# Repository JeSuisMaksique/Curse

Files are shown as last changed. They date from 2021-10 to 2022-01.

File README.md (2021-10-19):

# Curse
Репозиторий курсового проекта
Описание датчика.
Датчик замеряет температуру/влажность и отправляет данные по Wi-Fi с помощью модуля ESP-01S. При нажатии на кнопку можно отобразить текущие показания на OLED дисплее.

Датчика включает:
1. Плату обработки;
2. Модуль ESP-01S;
3. OLED дисплей.

Функции платы обработки:
1. Периодический опрос датчика AHT20 по i2c и получение данных о температуре и влажности;
2. Передача полученных данных с помощью модуля ESP-01S;
3. Периодичский контроль заряда аккумулятора с помощью АЦП. При низком заряде аккумклятора датчик передаёт информацию о разряде аккумуляора по Wi-Fi с помощью ESP-01S.

Основную часть времени модуль ESP-01S находится в режие сна и активируется только для передачи данных

Плата обработки (v.0.1):
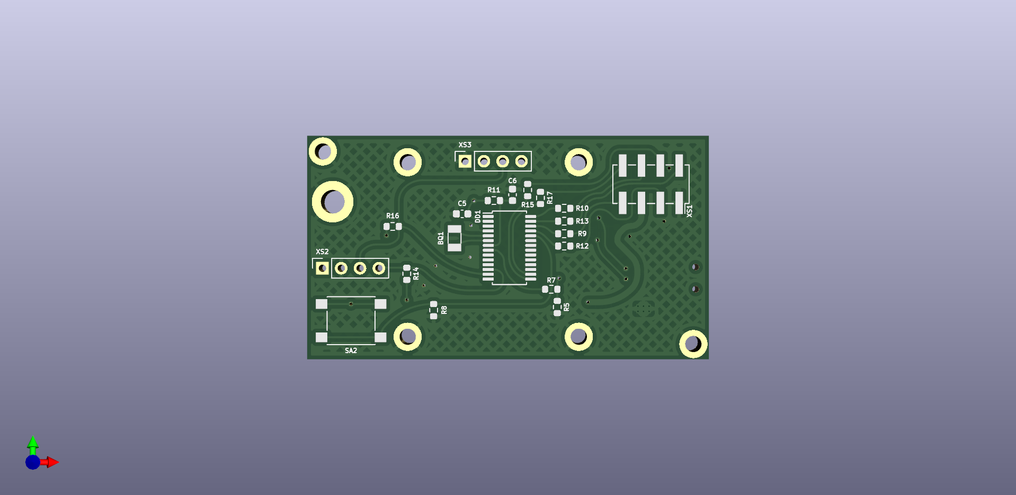
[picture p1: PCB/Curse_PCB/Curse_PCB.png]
PCB_Render


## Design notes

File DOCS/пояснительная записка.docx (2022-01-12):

# Аннотация

В данной работе рассматривается задача разработки датчика для замера температуры и влажности с последующей отправкой данных по Wi-Fi с помощью модуля ESP-01S, либо отображении этих данных на встроенном OLED дисплее.

Составляется структурная и принципиальная схема устройства, производится подбор элементной базы, трассировка, размещение элементов на плате, создание прототипа корпуса прибора, а также сравнение с уже имеющимися прототипами на рынке и с серийными аналогами.

# Лист технического задания

1. Прибор – устройство для замера температуры и влажности;

2. Назначение – измерение температуры и влажности окружающей среды;

3. Тип датчика или сенсора – датчик измерения температуры и влажности;

4. Тип микроконтроллера – MSP430F2112;

5. АЦП – измерение напряжения аккумулятора для контроля разряда;

6. Устройство ввода – кнопки;

7. Устройство вывода – OLED дисплей;

8. Интерфейс связи с ПК – Wi-Fi;

9. Тип питания – автономное;

10. Габариты устройства не должны превышать 80 мм х 36 мм х 27 мм (ШВГ);

# Введение

С помощью датчика температуры и влажности можно обеспечить комфортные условия в доме, потому что его показатели помогут вовремя проветривать комнаты, регулировать отопительную систему. В настоящее такие датчики используются в жилых и нежилых помещениях. Под целевым назначением нежилого помещения обычно понимается вид деятельности, для ведения которой будет использовано данное помещение, например: торговые, производственные, складские, офисные, медицинские, образовательные и спортивные помещения. К жилым помещениям относятся: жилой дом, квартира или комната.

Датчик – небольшая микросхема, которая оснащена термистором и емкостным определителем влажности. Эти элементы и определяют влажность и температуру воздуха.

Датчики температуры и влажности широко применяются на различных промышленных предприятиях. Этот прибор используются для автоматизации и диспетчеризации, различного рода помещений и теплиц, а также технологических процессов. В настоящее время часто используется в системе «Умный дом». С их помощью происходит измерение температуры и влажности в системах автоматического контроля и регулировка технологических процессов. Их задача состоит в получении данных об измеряемой величине, преобразовании и передаче полученных сигналов.

В рамках данного курсового проекта разрабатывается устройство измерения температуры и влажности с возможностью передачи данных по беспроводному каналу связи и возможностью индикации текущих показаний на встроенном OLED дисплее, выполненном на основе модулей AHT20 (датчик температуры и влажности), ESP-01S (Wi-Fi модуль) и WEA012864MX (дисплейный модуль фирмы «Winstar»).

# 1. Обзор рынка

Существует широкий спектр приборов для измерения температуры и влажности как проводных, так и работающих от батареек или аккумуляторов. Некоторые модели имеют особенности, такие как: беспроводное подключение к автоматическому регулированию климата в помещении, оповещение о изменении микроклимата на телефон или с помощью звукового сигнала, отображение даты и времени. Для сравнения с разработанным устройством были выбраны три модели датчиков, которые приведены в таблице 1. Модели подобраны по следующим характеристикам: имеют низкую стоимость, обладают базовым функционалом.

Таблица 1 – Сравнение приборов

Наименование | Xiaomi Mijia Bluetooth Hygrothermograph 2 | Xiaomi MiJia Miaomiaoce E-Ink | Thermo TA318

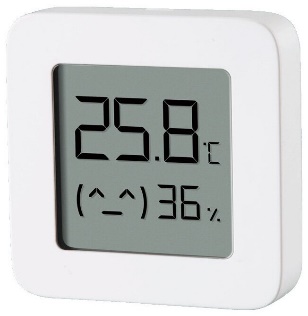
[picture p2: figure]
Метеостанция Xiaomi Mijia Bluetooth Hygrothermograph 2, белый
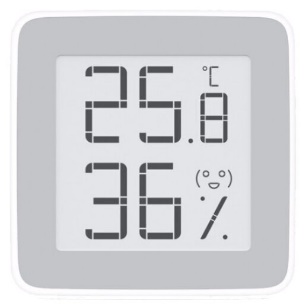
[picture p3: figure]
Метеостанция Xiaomi MiJia Miaomiaoce E-Ink, белый
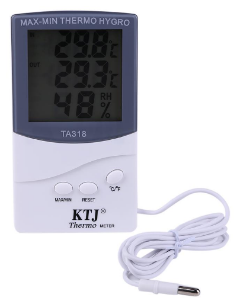
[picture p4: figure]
Метеостанция Thermo TA318 с выносным датчиком 1,5 м

Вид
Цена, руб. | 565 | 1140 | 970
Диапазон измерения температуры | -9-60° C | -0 - 60° C | -50 +70
Диапазон измерения влажности | 0-99.9% | - | -
Питание | автономное | автономное | автономное
Тип элемента питания | CR2032 | CR2032 | AAA
Расположение датчика | Внутреннее | Внутреннее | Выносной
Точность измерения температуры | - | 0.3° C | -
Точность измерения влажности | - | 3% | -
Беспроводной интерфейс | Bluetooth 4.2 BLE | Отсутствует | Отсутствует
Дополнительные функции | синхронизация со смартфоном | - | -

Большинство моделей на рынке представлены с дополнительными функциями. Прибор, разработанный в данном проекте, обладает только функциями измерения температуры и влажности и их дальнейшей отправкой по беспроводному каналу связи. Из-за того, что данное устройство будет являться штучным или мелкосерийным изделием, то стоимость будет гораздо выше, чем у массовых приборов такого же функционала.

# 2. Разработка устройства

Согласно техническому заданию, датчик температуры и влажности был разработан на базе модуля с датчиком температуры и влажности AHT20, OLED дисплея и модуля ESP-01S, которые подключены к микроконтроллеру MSP430F2112.

# 2.1 Структурная схема прибора и её описание

Устройство состоит из платы обработки с контроллером MSP430F2112, к которой подключены датчик AHT20, дисплейный модуль и Wi-Fi модуль ESP-01S. Структурная схема представлена на рисунке 1. Питание осуществляется от аккумулятора.

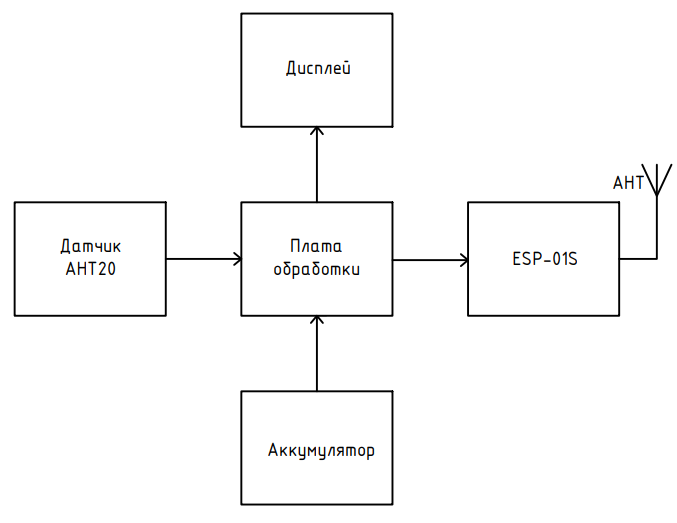
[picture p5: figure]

Рис. 1. Структурная схема устройства

# 2.2 Структура алгоритма программы для прибора

Большую часть времени устройство находится в режиме сна для экономии энергии. По таймеру один раз в минуту микроконтроллер опрашивает датчик температуры и влажности, и отправляет их на ПК по беспроводному каналу связи с помощью модуля ESP-01S. Также микроконтроллер периодически замеряет напряжение на аккумуляторе с помощью АЦП и, при низком напряжении, отправляет сигнал о низком заряде по беспроводному каналу связи. Также, при нажатии на кнопку происходит отображение текущих показаний на OLED дисплее в течение 10 секунд. Блок-схема алгоритма представлена на рисунке 2.

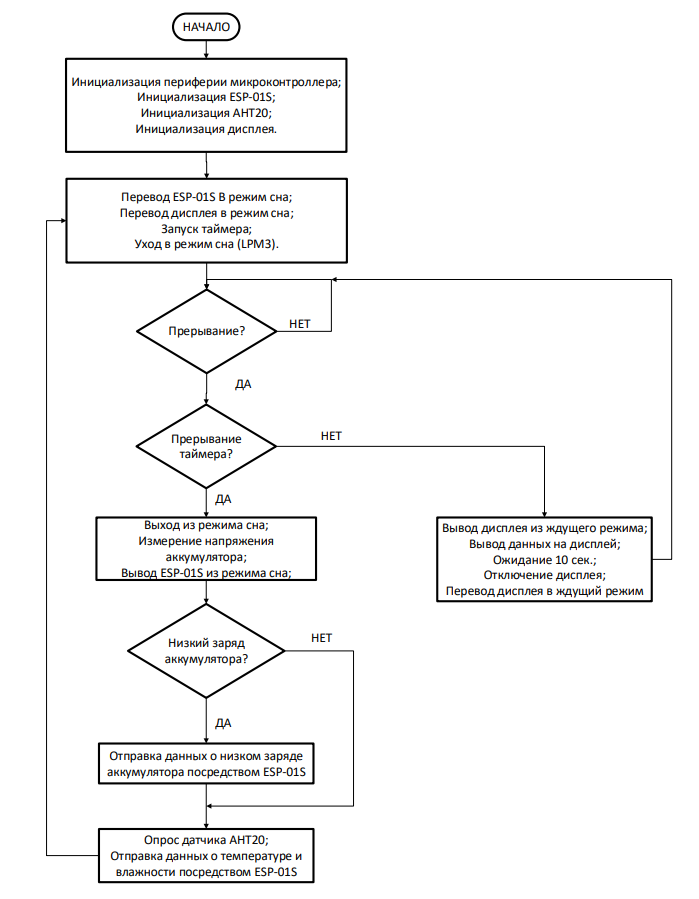
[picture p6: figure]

Рис. 2. Блок-схема алгоритма

# 2.3 Источник питания и общее потребление

Устройство питается с помощью литий-полимерного аккумулятора типоразмера 803040. В схеме предусмотрена возможность осуществлять зарядку аккумулятора через Micro USB разъём. Для этого в схеме (Рис. 3) присутствует микросхема для заряда BQ21040 «Texas Instruments» (DA2), а также защита от переразряда и перезаряда с помощью микросхемы BQ29737 «Texas Instruments» (DA1) и транзисторной сборки BUK9K5R1-30E «Nexperia». Микросхема DA1 замеряет напряжение аккумулятора и при слишком низком или слишком высоком напряжении отключает его от цепи для предотвращения нанесения ущерба аккумулятору.

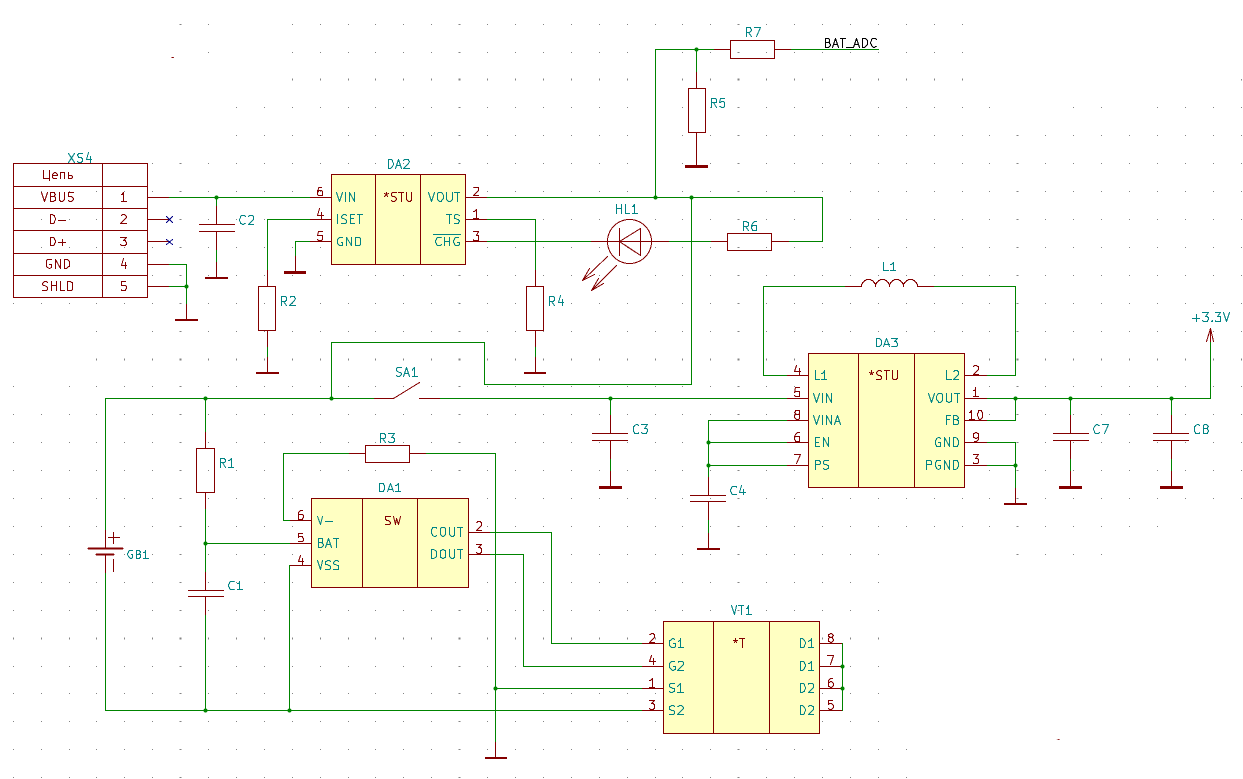
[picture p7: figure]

Рис. 3. Схема питания

За формирование рабочего напряжения 3,3 В отвечает микросхема TPS63061 «Texas Instruments» (DA3). TPS63061 представляют собой решение для питания от трех- и шестиэлементных щелочных, никель-кадмиевых или никель-металлгидридных аккумуляторов, а также одноэлементных или двухэлементных литий-ионных или литий-полимерных аккумуляторов. Выходные токи могут достигать 2 А при использовании двухэлементной литий-ионной или литий-полимерной батареи и разряжаться до 5 В или ниже. Понижающе-повышающий преобразователь основан на контроллере с фиксированной частотой и широтно-импульсной модуляцией (ШИМ), использующем синхронное выпрямление для достижения максимальной эффективности. При низких токах нагрузки преобразователь переходит в режим энергосбережения, чтобы поддерживать высокий КПД в широком диапазоне токов нагрузки. Режим энергосбережения можно отключить, заставив преобразователь работать на фиксированной частоте переключения. Максимальный средний ток в ключах ограничен типичным значением 2,25 А. Выходное напряжение программируется с помощью внешнего резисторного делителя или фиксируется внутри микросхемы[ссылка].

Основные потребители энергии:

1) Микроконтроллер MSP430F2112;
2) Дисплейный модуль WEA012864MX;
3) Wi-Fi модуль ESP-01S;
4) Модуль измерения температуры и влажности AHT20.

Потребление MSP430F2112. Основную часть времени контроллер находится в режиме энергосбережения (LPM3), в котором потребление составляет примерно 0,8 мкА при напряжении питания 3,3 В, с периодическим выходом в активный режим, в котором потребление составляет 450 мкА при напряжении питания 3,3 В. Среднее потребление при нахождении в активном режиме 10 секунд каждую минуту составит 45,72 мкА при напряжении питания 3,3 В.

Потребление модуля ESP-01S. По аналогии с MSP430 модуль ESP-01S находится в режиме сна, выходя из него только для передачи данных. В режиме сна потребление составляет 20 мкА при напряжении питания 3,3 В. В активном режиме при мощности передатчика 20 мВт (13 дБм) потребление составляет 120 мА при напряжении питания 3,3 В. В активный режим передатчик переходит раз в минуту и находится в нём в среднем одну секунду благодаря чему среднее потребление составит 2,05 мА при напряжении питания 3,3 В.

Потребление модуля AHT20. В режиме бездействия потребление составляет не более 250 нА при напряжении питания 3,3 В. В режиме измерения потребление составляет 23 мкА при напряжении питания 3,3 В. Режим измерения длится 80 мс и производится один раз в минуту. Среднее потребление при этом составит примерно 280 нА при напряжении питания 3,3 В.

Потребление дисплейного модуля WEA012864MX. В режиме ожидания драйвер дисплея SSD1306 потребляет не более 10 мкА при напряжении питания 3,3 В. В активном режиме дисплейный модуль потребляет 15 мА при напряжении питания 3,3 В при 50% заполнении дисплея. Так как периодическое включение дисплея отсутствует, то среднее потребление составляет 10 мкА при напряжении питания 3,3 В.

Данные о потреблении основных элементов представлены в таблице 2.

Таблица 2 – Потребления основных элементов

Потребитель | Потребление в ждущем режиме при напряжении 3,3 В, мА | Потребление в активном режиме при напряжении 3,3 В, мА | Среднее потребление при напряжении 3,3 В, мА | Среднее потребление, мВт
MSP430F2112 | 0,0008 | 0,45 | 0,0457 | 0,151
ESP-01S | 0,02 | 120 | 2,02 | 6,7
AHT20 | 0,00025 | 0,023 | 0,0003 | 0,0008
WEA012864MX | 0,01 | 15 | 0,01 | 0,033

Таким образом примерное среднее потребление устройства составляет примерно 6,85–7 мВт.

Предполагается использование литий-полимерного аккумулятора 803040-950 ёмкостью 950 мА/ч и номинальным напряжением 3.7 В, или 3,515 Вт/ч. Без учёта саморазряда аккумулятора и в случае соответствия номинальной ёмкости время автономной работы устройства от одного заряда составит примерно 513 часов или 21 день и 9 часов в случае измерения и передачи данных один раз в минуту. Время автономной работы можно увеличить путём увеличения интервала измерения и передачи данных. При этом максимальное потребление тока может составить примерно 136 мА при напряжении питания 3,3 В.

# 2.4 Дисплей

Дисплейный модуль WEA012864MX «Winstar» (Рис. 4) построен на базе OLED дисплея и драйвера SSD1306 [ссылка]. Дисплей подключается к шине I2C.

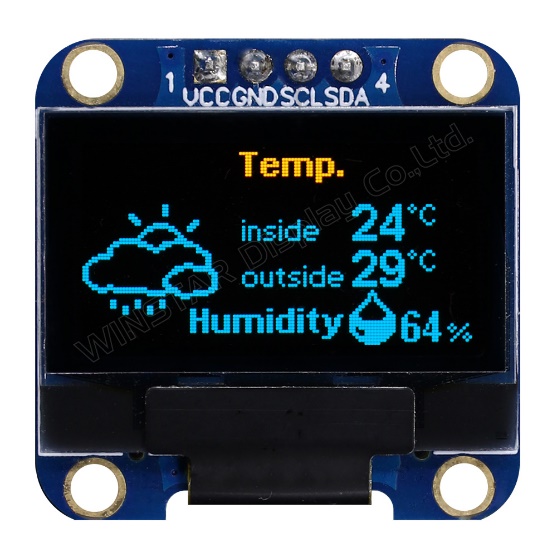
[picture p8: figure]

Рис. 4. Дисплейный модуль WEA012864MX

# 2.5 Модуль датчика влажности и температуры

Плата модуля содержит датчик температуры и относительной влажности AHT20 и его обвязку (рисунок 5). Датчик выдает цифровые сигнала в стандартном формате I2C. AHT20 оснащен микросхемой, улучшенным полупроводниковым емкостным датчиком влажности и стандартным встроенным датчиком температуры.

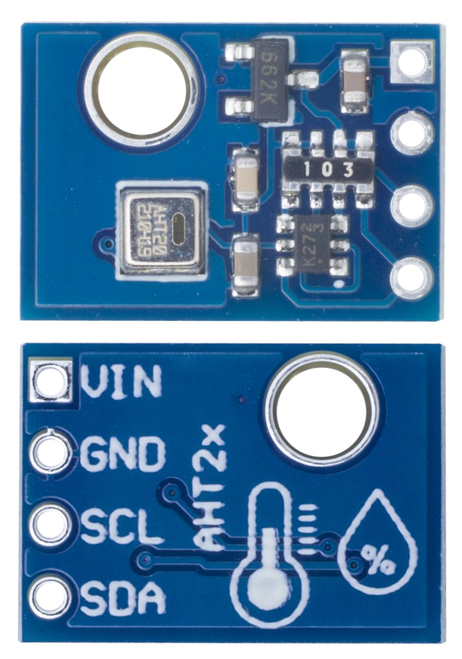
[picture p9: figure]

Рис. 5. Модуль датчика АНТ20

Технические характеристики[ссылка]:

1) Потребляемый ток – 23 мкА (в режиме измерения), в режиме покоя: 0,25 мкА;
2) Напряжение питания: 2–5,5 В;
3) Измеряет влажность в диапазоне от 0% до 100%. Погрешность может составлять до 2%;
4) Измеряет температуру в интервале от -40 до 85 °C (точность – 0,3 °C)

# 2.6 Микроконтроллер

Для обработки информации и взаимодействия со всеми элементами устройства был выбран микроконтроллер MSP430F2112 «Texas Instruments» (рисунок 6).

Данный микроконтроллер имеет следующие характеристики [ссылка]:

1) Диапазон напряжения питания: от 1,8 до 3,6 В;
2) Сверхнизкое энергопотребление (Активный режим: 250 мкА при 1 МГц, 2,2 В; Режим ожидания: 0,7 мкА);
3) Сверхбыстрый выход из режима ожидания менее чем за 1 мкс;
4) 10-битный аналого-цифровой преобразователь со скоростью 200 тыс/с с внутренним эталоном, выборкой и хранением, автосканированием и контроллером передачи данных;
5) Универсальный последовательный интерфейс связи (UART, SPI, I2C);
6) 2 КБ + 256 Б флэш-памяти и 256 байт ОЗУ.

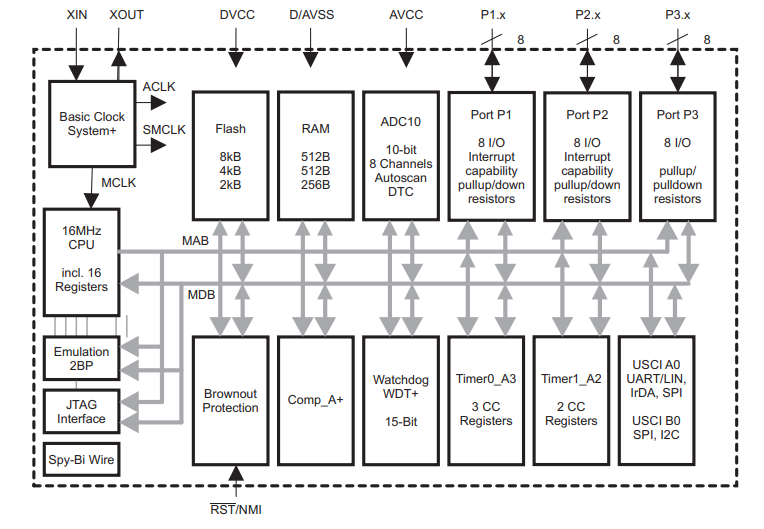
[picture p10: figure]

Рисунок 6 – Блок-схема микроконтроллера MSP430F2112

Разъёма программирования на плате не предусмотрено, так как предполагается, что программа будет записываться на этапе изготовления.

# 2.7 Модуль ESP-01S

ESP-01S — плата-модуль WiFi на базе популярного чипсета ESP8266EX (Рис. 7). На борту платы находится микросхема Flash-памяти объёмом 2 МБ, чип ESP8266EX, кварцевый резонатор, два индикаторных светодиода и микрополосковая антенна на верхнем слое печатной платы. Flash-память необходима для хранения программного обеспечения. При каждом включении питания, ПО автоматически загружается в чип ESP8266EX [ссылка].

По умолчанию модуль настроен на работу через «AT-команды». Управляющая плата посылает команды — Wi-Fi модуль выполняет соответствующую операцию.

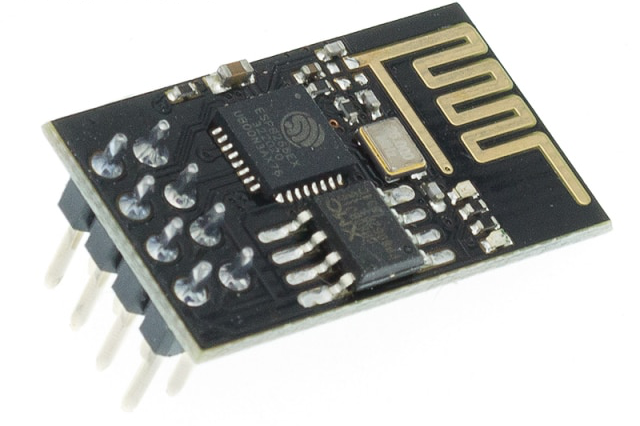
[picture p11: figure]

Рис. 7. Модуль ESP-01S

# 2.8. Разработка конструктива корпуса

Плату с размещенными на ней элементами необходимо поместить в корпус (Рис. 8). Для изготовления корпуса датчика температуры и влажности выбран АБС-пластик. АБС-пластик – ударопрочная техническая термопластическая смола на основе сополимера акрилонитрила с бутадиеном и стиролом. Этот вид пластмассы является нетоксичным и ударостойким. Предполагается использовать пластмассу белого цвета. Чертёж корпуса представлен в приложении ?.

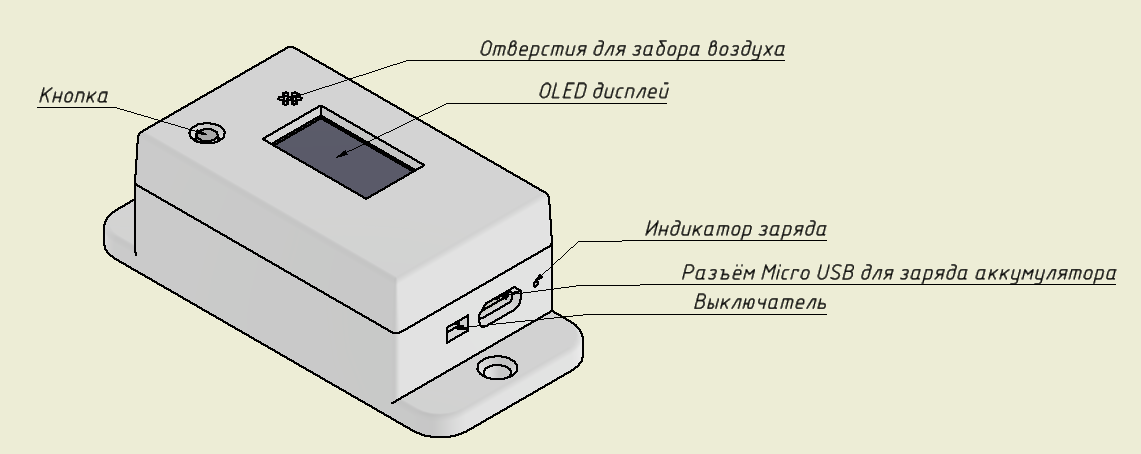
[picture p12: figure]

Рис. 8. Корпус

# 3. Расчет стоимости

Была рассчитана стоимость одного изделия из расчёта штучного производства и производства партии в 1000 штук.

Информация о стоимости ЭРИ взята с сайтов «Чип и Дип» (https://www.chipdip.ru/), «ДКО Электронщик» (https://www.electronshik.ru/) и «АлиЭкспресс» (https://aliexpress.ru/). Данные о стоимости ЭРИ представлены в таблице 3.

Таблица 3 – Стоимость ЭРИ

Наименование | Кол-во | Цена для 1 изделия | Цена для 1000 изделий | Итого для 1 изделия | Итого для 1000 изделий | Примечаиние
1 | 2 | 3 | 4 | 5 | 6 | 7
Кварцевый резонатор 32.768 kHz 03215C2 | 1 | 68,00 | 50,00 | 68 | 50000 | Чип и Дип
0.1 мкФ-NP0-50В ±10% 0603 | 3 | 12,00 | 2,00 | 36 | 6000 | Чип и Дип
1 мкФ-NP0-16В ±10% 0805 | 1 | 8,00 | 2,60 | 8 | 2600 | Чип и Дип
10 мкФ-NP0-16В ±5% 0805 | 3 | 10,00 | 4,20 | 30 | 12600 | Чип и Дип
2200 пФ-NP0-50В ±5% 0603 | 1 | 3,00 | 0,77 | 3 | 770 | Чип и Дип
BQ21040 | 1 | 232,02 | 114,58 | 232,02 | 114580 | ДКО Электронщик
BQ29737 | 1 | 48,34 | 16,86 | 48,34 | 16860 | ДКО Электронщик
MSP430F2112IPW | 1 | 110,00 | 137,70 | 110 | 137700 | ДКО Электронщик
TPS63031 | 1 | 126,00 | 126,00 | 126 | 126000 | ДКО Электронщик
TO-1608BC-MRE | 1 | 8,00 | 8,00 | 8 | 8000 | Чип и Дип

Продолжение таблицы 3
1 | 2 | 3 | 4 | 5 | 6 | 7
VLS252010CX-1R5M-1 | 1 | 59,65 | 32,79 | 59,65 | 32790 | ДКО Электронщик
1,0 кОм ±1% 0603 | 1 | 3,00 | 0,48 | 3 | 480 | Чип и Дип
1,5 кОм ±5% 0603 | 1 | 3,00 | 0,48 | 3 | 480 | Чип и Дип
10 кОм ±5% 0603 | 5 | 3,00 | 0,48 | 15 | 2400 | Чип и Дип
100 кОм ±5% 0603 | 1 | 3,00 | 0,48 | 3 | 480 | Чип и Дип
2,2 кОм ±5% 0603 | 1 | 3,00 | 0,48 | 3 | 480 | Чип и Дип
330 Ом ±5% 0603 | 1 | 3,00 | 0,48 | 3 | 480 | Чип и Дип
47 кОм ±5% 0603 | 1 | 3,00 | 0,48 | 3 | 480 | Чип и Дип
510 Ом ±5% 0603 | 6 | 3,00 | 0,48 | 18 | 2880 | Чип и Дип
PCM12SMTR | 1 | 72,50 | 56,00 | 72,5 | 56000 | ДКО Электронщик
2-1977223-9 | 1 | 60,09 | 23,72 | 60,09 | 23720 | ДКО Электронщик
BUK9K5R1-30E | 1 | 44,87 | 42,07 | 44,87 | 42070 | ДКО Электронщик
DS-1023 - 2x4 | 1 | 4,12 | 2,76 | 4,12 | 2760 | ДКО Электронщик
DS-1023 - 1x4 | 2 | 1,70 | 1,30 | 3,4 | 2600 | ДКО Электронщик
47346-0001 | 1 | 20,00 | 15,20 | 20 | 15200 | ДКО Электронщик
Аккумулятор LP803040 | 1 | 398,84 | 398,84 | 398,84 | 398840 | АлиЭкспресс
ESP-01S | 1 | 78,69 | 78,69 | 78,69 | 78690 | АлиЭкспресс
AHT20 | 1 | 78,69 | 78,69 | 78,69 | 78690 | АлиЭкспресс
WEA012864MX | 1 | 437,08 | 334,96 | 437,08 | 334960 | ДКО Электронщик

Стоимость ЭРИ при изготовлении одного экземпляра составит 1978 рублей 29 копеек. Стоимость ЭРИ при изготовлении 1000 штук составит 1549590 рублей или 1549 рублей 59 копеек за штуку.

Стоимость изготовления печатных плат в Китае (сервис PCBWay) составит 6307 рублей 91 копейку с учётом доставки при изготовлении одного экземпляра (рис. 9).

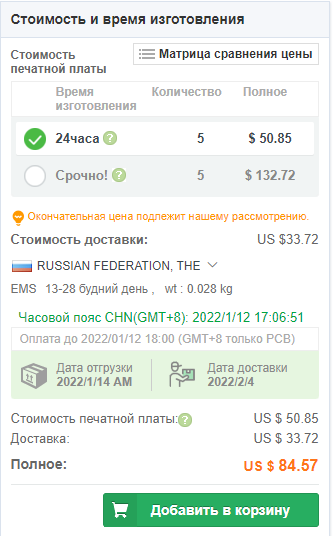
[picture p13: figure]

Рис. 9. Расчёт стоимости печатных плат для штучного изготовления

При изготовлении 1000 шт стоимость составит 28597 рублей 4 копейки с учётом доставки или 28 рублей 60 копеек за штуку (рис. 10).

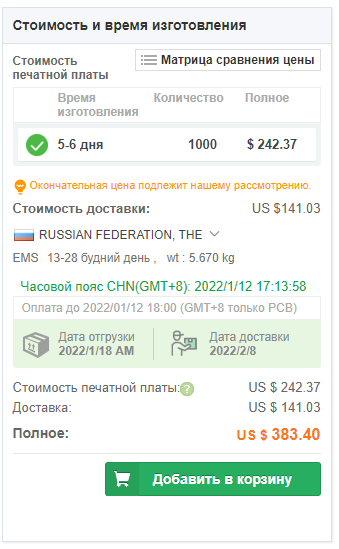
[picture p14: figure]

Рис. 10. Расчёт стоимости печатных плат для изготовления 1000 шт.

Стоимость монтажа одной платы составит 2237 рублей 64 копейки (рис. 11).

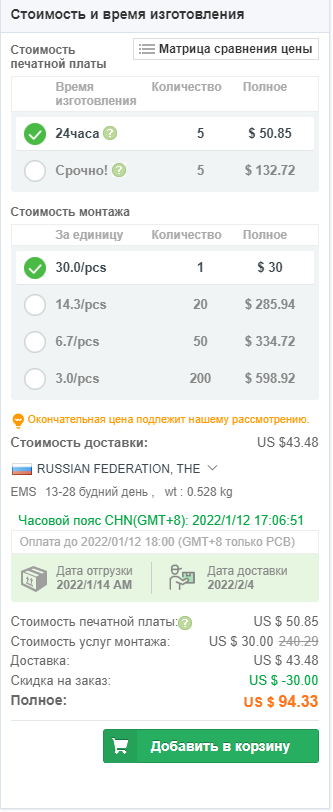
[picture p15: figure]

Рис. 11. Расчёт стоимости монтажа одной печатной платы

Стоимость монтажа 1000 штук составит 82409 рублей 30 копеек или 82 рубля 41 копейка за штуку (рис. 12).

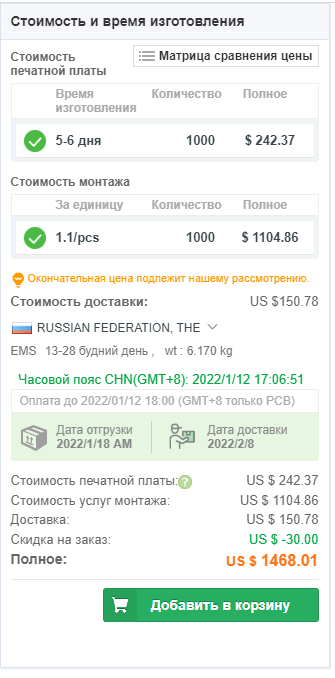
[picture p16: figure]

Рис. 12. Расчёт стоимости монтажа 1000 печатных плат

Изготовление одного корпуса обойдётся в 1570 рублей 19 копеек (рис. 13).

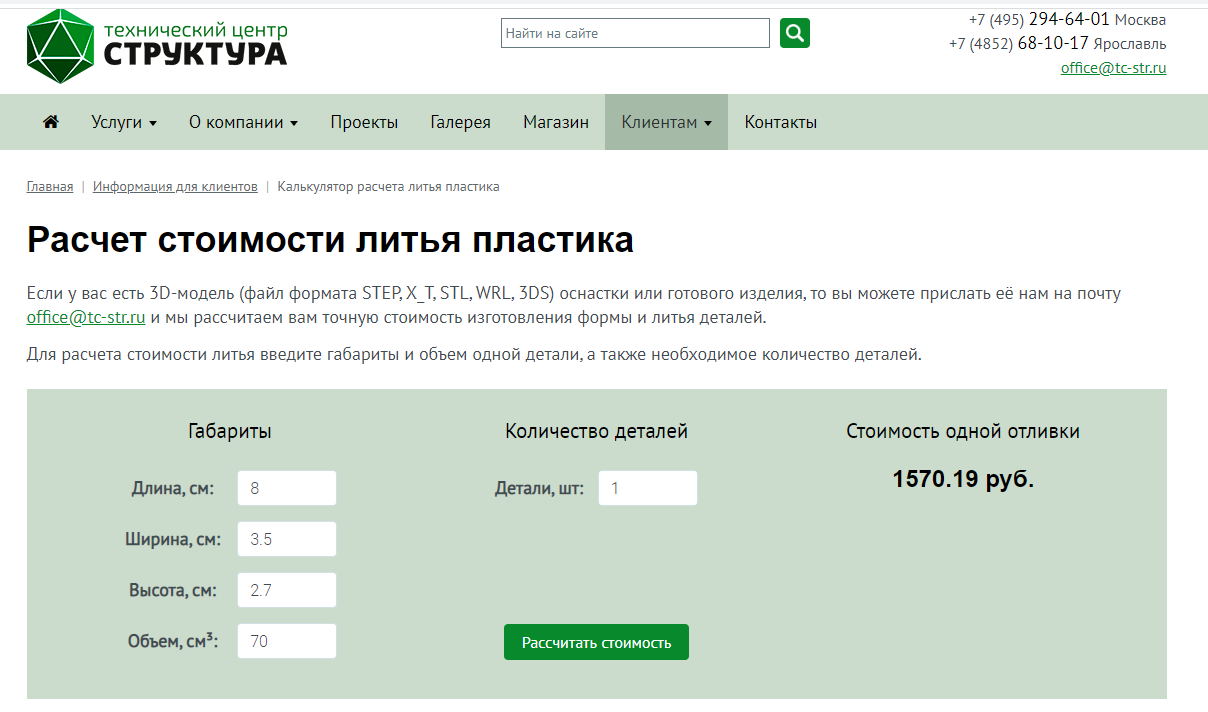
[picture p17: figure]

Рис. 13. Расчёт стоимости изготовления одного корпуса

Изготовление 1000 корпусов обойдётся в 258050 рублей или 258 рублей 5 копеек за штуку (рис. 14).

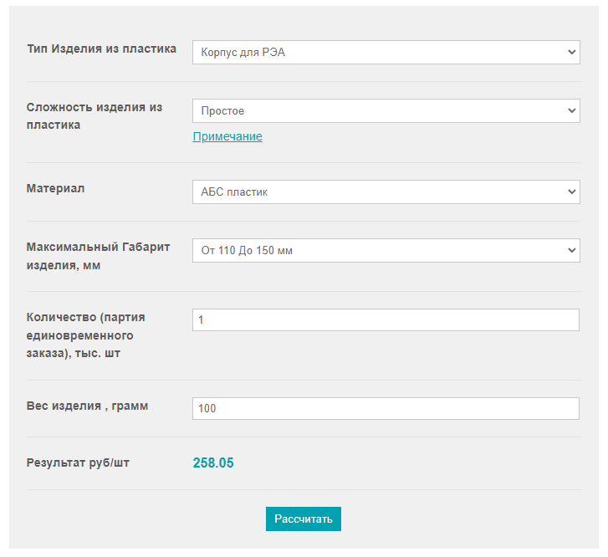
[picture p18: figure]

Рис. 14. Расчёт стоимости изготовления 1000 корпусов

Упаковочный материал, а именно коробка картонная и защита из пенопласта будут стоить 17 и 8 рублей соответственно.

По полученным данным была сведена таблица стоимости изготовления устройства (таблица 4).

Таблица 4 – Стоимость изготовления

Вид затрат | Стоимость для штучного изготовления, руб | Стоимость для изготовления 1000 штук, руб
ЭРИ | 1978,29 | 1549590
Печатные платы | 6307,91 | 28597,04
Монтаж | 2237,64 | 82409,30
Корпус | 1570,19 | 258050
Упаковка | 25 | 25000

Итого затраты на изготовление одного экземпляра устройства составляют 12119 рублей 3 копейки. Затраты на изготовление 1000 единиц составляют 1943646 рублей 34 копейки или 1943 рубля 65 копеек.

# Заключение

В ходе данного курсового проекта был разработан прибор — устройство измерения температуры и влажности. Разработана структурная схема устройства, принципиальная электрическая схема, схема печатной платы, схема предполагаемого корпуса разработанного устройства. Проведен расчет стоимости устройства и анализ аналогов, уже существующих на рынке.

Разработанное в ходе курсового проекта устройство получилось существенно дороже существующих на рынке аналогов. Также при использовании модульной системы значительно выросли габариты устройства

# Список литературы

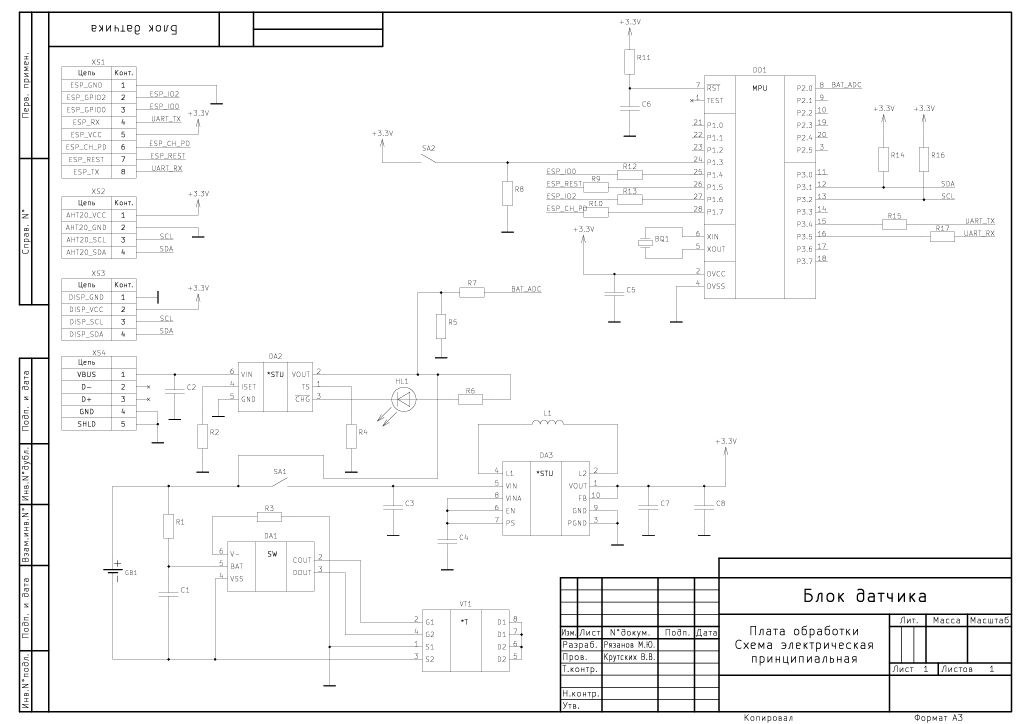
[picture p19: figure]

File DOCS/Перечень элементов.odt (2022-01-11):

Поз. обозна- чение | Наименование | Кол. | Примечание
| Кварцевые резонаторы
BQ1 | 32.768 kHz 03215C2 | 1
| Конденсаторы
C1 | 0.1 мкФ-X7R-50В ±10% 0603 | 1
C2 | 1 мкФ-X7R-16В ±10% 0805 | 1
C3 | 10 мкФ-X5R-16В ±10% 0805 | 1
C4, C5 | 0.1 мкФ-X7R-50В ±10% 0603 | 2
C6 | 2200 пФ-NP0-50В ±5% 0603 | 1
C7, C8 | 10 мкФ-X5R-16В ±10% 0805 | 2
| Микросхемы
DA1 | BQ29737 WSON-6 | 1
DA2 | BQ21040 SOT-23-6 | 1
DA3 | TPS63031 WSON-10 | 1
DD1 | MSP430F2112IPW TSSOP-28 | 1
| Диоды
HL1 | TO-1608BC-MRE | 1
| Катушки индуктивности
L1 | VLS252010CX-1R5M-1 1,5 мкГн 2010 | 1
| Резисторы
R1 | 330 Ом ±5% 0603 | 1
R2 | 1,0 кОм ±1% 0603 | 1
R3 | 2,2 кОм ±5% 0603 | 1
R4, R5 | 10 кОм ±5% 0603 | 2
R6 | 1,5 кОм ±5% 0603 | 1
R7 | 10 кОм ±5% 0603 | 1
R8 | 100 кОм ±5% 0603 | 1
R9, R10 | 510 Ом ±5% 0603 | 2
R11 | 47 кОм ±5% 0603 | 1
R12, R13 | 510 Ом ±5% 0603 | 2
R14 | 10 кОм ±5% 0603 | 1
R15 | 510 Ом ±5% 0603 | 1
R16 | 10 кОм ±5% 0603 | 1
R17 | 510 Ом ±5% 0603 | 1
| Кнопки
SA1 | PCM12SMTR | 1
SA2 | 2-1977223-9 | 1
| Транзисторы
VT1 | BUK9K5R1-30E LFPAK56D | 1
| Разъёмы
XS1 | DS-1023 - 2x4 | 1
XS2, XS3 | DS-1023 - 1x4 | 2
XS4 | 47346-0001 | 1
| Прочее
GB1 | Аккумулятор LP803040 | 1

Плата обработки Перечень элементов Блок датчика Лит. Лист 1 Листов 3 Разраб. Пров. Н. контр. Утв. Рязанов М.Ю. Крутских В.В. Изм. Лист № докум. Подп. Дата Инв. № подл. Подп. и дата Взам. инв. № Инв. № дубл. Подп. и дата Копировал Формат А4

Плата обработки Перечень элементов Блок датчика Лит. Лист 0 Листов 3 Разраб. Пров. Н. контр. Утв. Рязанов М.Ю. Крутских В.В. Изм. Лист № докум. Подп. Дата Инв. № подл. Подп. и дата Взам. инв. № Инв. № дубл. Подп. и дата Справ. № Перв. примен. Копировал Формат А4

Плата обработки Перечень элементов Блок датчика Лит. Лист 0 Листов 3 Разраб. Пров. Н. контр. Утв. Рязанов М.Ю. Крутских В.В. Изм. Лист № докум. Подп. Дата Инв. № подл. Подп. и дата Взам. инв. № Инв. № дубл. Подп. и дата Копировал Формат А4

Блок датчика Лист 3 Изм. Лист № докум. Подп. Дата Инв. № подл. Подп. и дата Взам. инв. № Инв. № дубл. Подп. и дата Копировал Формат А4

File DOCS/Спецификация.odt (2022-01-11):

Формат | Зона | Поз. | Обозначение | Наименование | Кол. | Приме- чание
| | | | Документация
| | | Блок датчикаСБ | Сборочный чертёж
A3 | | | Блок датчика | Схема электрическая
| | | | принципиальная
A4 | | | Блок датчика | Перечень элементов
| | | | Детали
| | 1 | | Плата печатная | 1
| | | | Прочие изделия
| | 2 | | Кварцевый резонатор 32.768 kHz | 1 | BQ1
| | | | 03215C2
| | | | Конденсаторы
| | 3 | | 0.1 мкФ-X7R-50В ±10% 0603 | 3 | C1, C4, C5
| | 4 | | 1 мкФ-X7R-16В ±10% 0805 | 1 | C2
| | 5 | | 10 мкФ-X5R-16В ±10% 0805 | 3 | C3, C7, C8
| | 6 | | 2200 пФ-NP0-50В ±5% 0603 | 1 | C6
| | | | Микросхемы
| | 7 | | BQ21040 SOT-23-6 | 1 | DA2
| | 8 | | BQ29737 WSON-6 | 1 | DA1
| | 9 | | MSP430F2112IPW TSSOP-28 | 1 | DD1
| | 10 | | TPS63031 WSON-10 | 1 | DA3
| | 11 | | Диод TO-1608BC-MRE | 1 | HL1
| | 12 | | Катушка индуктивности | 1 | L1
| | | | VLS252010CX-1R5M-1 1,5 мкГн 2010
| | | | Резисторы
| | 13 | | 1,0 кОм ±1% 0603 | 1 | R2
| | 14 | | 1,5 кОм ±5% 0603 | 1 | R6
| | 15 | | 10 кОм ±5% 0603 | 5 | R4, R5, R7,
| | | | | | R14, R16
| | 16 | | 100 кОм ±5% 0603 | 1 | R8
| | 17 | | 2,2 кОм ±5% 0603 | 1 | R3
| | 18 | | 330 Ом ±5% 0603 | 1 | R1
| | 19 | | 47 кОм ±5% 0603 | 1 | R11
| | 20 | | 510 Ом ±5% 0603 | 6 | R9, R10,
| | | | | | R12, R13,
| | | | | | R15, R17
| | | | Кнопки
| | 21 | | PCM12SMTR | 1 | SA1
| | 22 | | 2-1977223-9 | 1 | SA2
| | 23 | | Транзистор BUK9K5R1-30E LFPAK56D | 1 | VT1
| | | | Разъёмы
| | 24 | | DS-1023 - 2x4 | 1 | XS1
| | 25 | | DS-1023 - 1x4 | 2 | XS2, XS3
| | 26 | | 47346-0001 | 1 | XS4
| | 27 | | Аккумулятор LP803040 | 1 | GB1

Плата обработки Спецификация Блок датчика Лит. Лист 1 Листов 2 Разраб. Пров. Н. контр. Утв. Рязанов М.Ю. Крутских В.В. Изм. Лист № докум. Подп. Дата Инв. № подл. Подп. и дата Взам. инв. № Инв. № дубл. Подп. и дата Копировал Формат А4

Плата обработки Спецификация Блок датчика Лит. Лист 0 Листов 2 Разраб. Пров. Н. контр. Утв. Рязанов М.Ю. Крутских В.В. Изм. Лист № докум. Подп. Дата Инв. № подл. Подп. и дата Взам. инв. № Инв. № дубл. Подп. и дата Справ. № Перв. примен. Копировал Формат А4

Плата обработки Спецификация Блок датчика Лит. Лист 0 Листов 2 Разраб. Пров. Н. контр. Утв. Рязанов М.Ю. Крутских В.В. Изм. Лист № докум. Подп. Дата Инв. № подл. Подп. и дата Взам. инв. № Инв. № дубл. Подп. и дата Копировал Формат А4

Блок датчика Лист 2 Изм. Лист № докум. Подп. Дата Инв. № подл. Подп. и дата Взам. инв. № Инв. № дубл. Подп. и дата Копировал Формат А4

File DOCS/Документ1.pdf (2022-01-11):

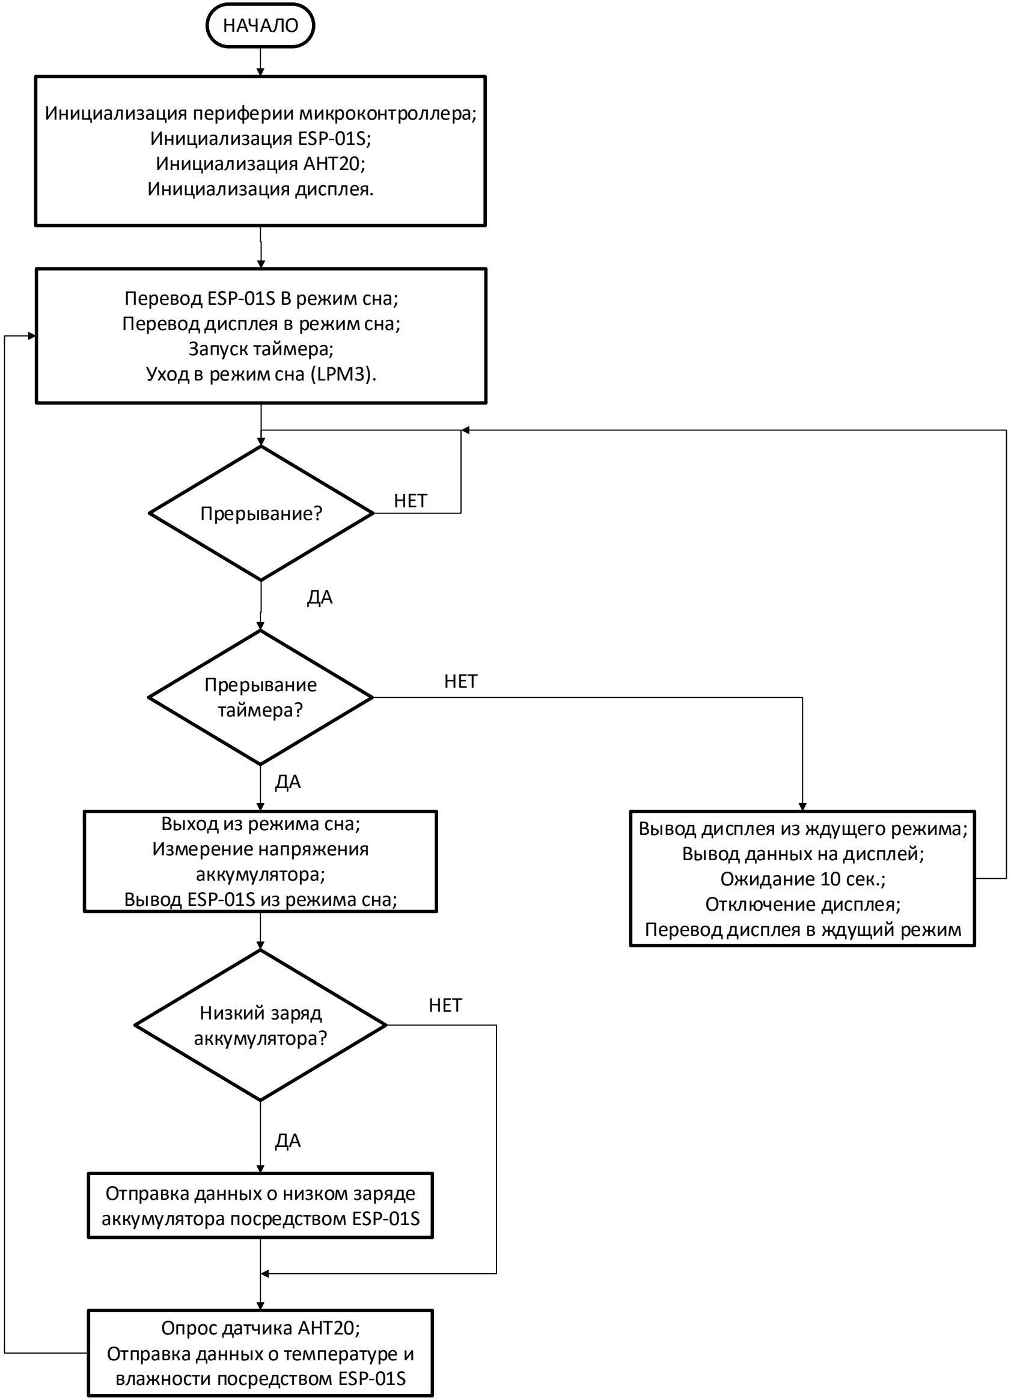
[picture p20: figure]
НАЧАЛО; Инициализация периферии микроконтроллера; Инициализация ESP-01S; Инициализация AHT20; Инициализация дисплея.; Перевод ESP-01S В режим сна; Перевод дисплея в режим сна; Запуск таймера; Уход в режим сна (LPM3).; Прерывание?; Прерывание таймера?; НЕТ; Выход из режима сна; Измерение напряжения аккумулятора; Вывод ESP-01S из режима сна;; Низкий заряд аккумулятора?; Отправка данных о низком заряде аккумулятора посредством ESP-01S; Опрос датчика AHT20; Отправка данных о температуре и влажности посредством ESP-01S; Вывод дисплея из ждущего режима; Вывод данных на дисплей; Ожидание 10 сек.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

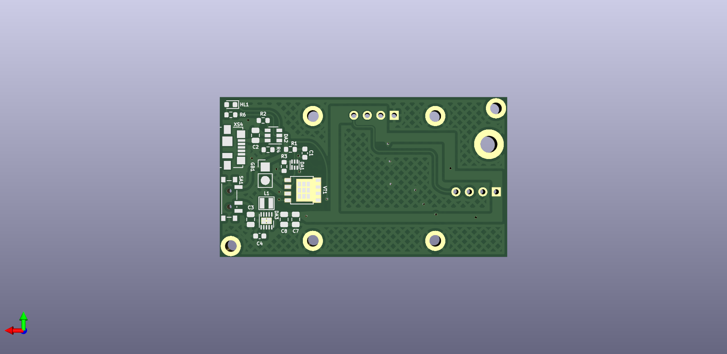
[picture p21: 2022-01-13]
PCB/Curse_PCB/Curse_PCB2.png

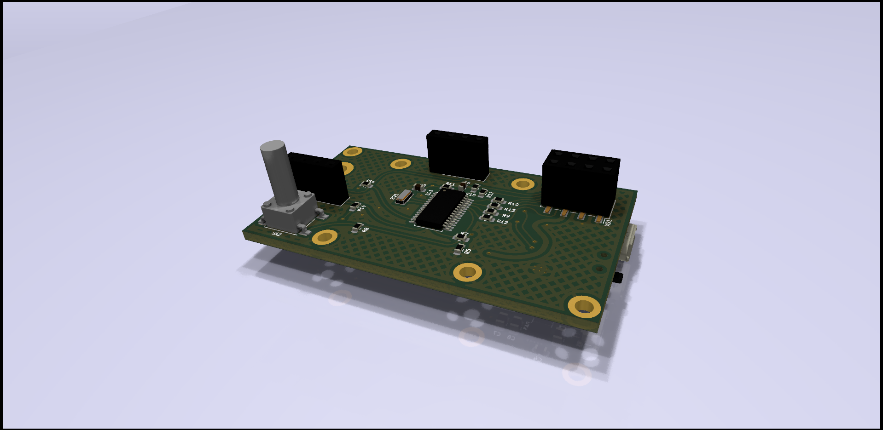
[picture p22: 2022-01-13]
PCB/Curse_PCB/Curse_PCB3.png

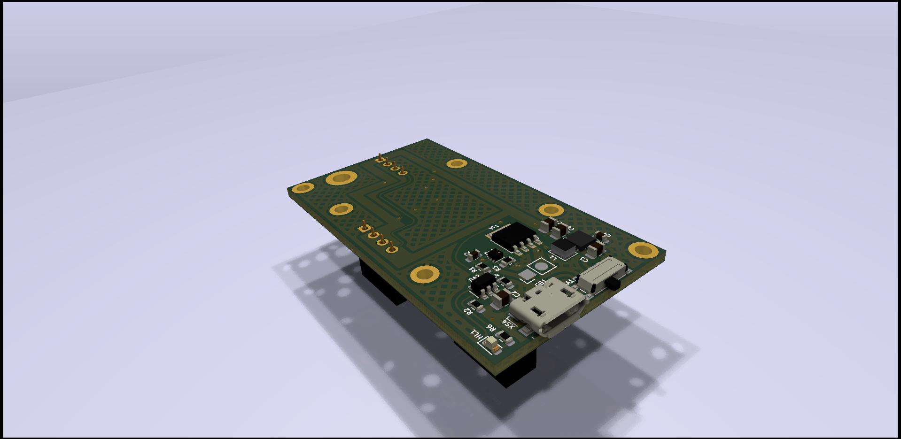
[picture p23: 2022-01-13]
PCB/Curse_PCB/Curse_PCB4.png

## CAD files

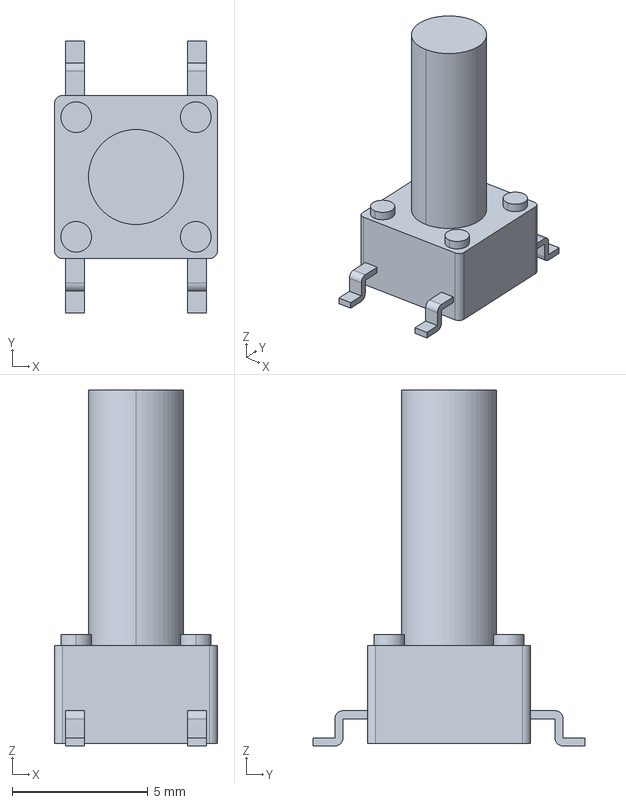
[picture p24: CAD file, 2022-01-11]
PCB/Curse_PCB/3d/c-2-1977223-9-b-3d.stp
6.00 x 10.0 x 13.1 mm

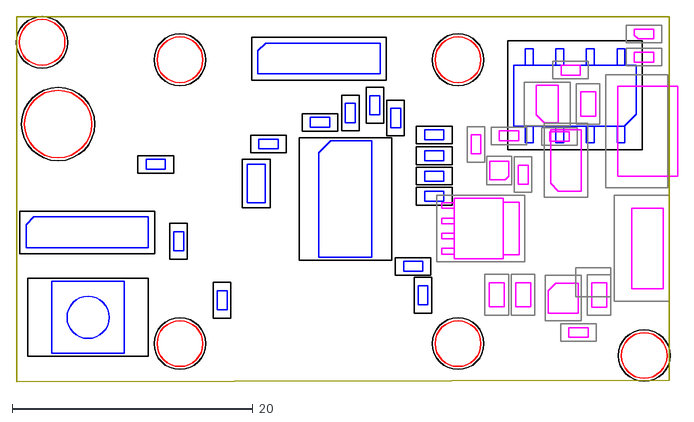
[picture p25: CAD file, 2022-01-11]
PCB/Curse_PCB/Curse_PCB.dxf
54.9 x 30.3

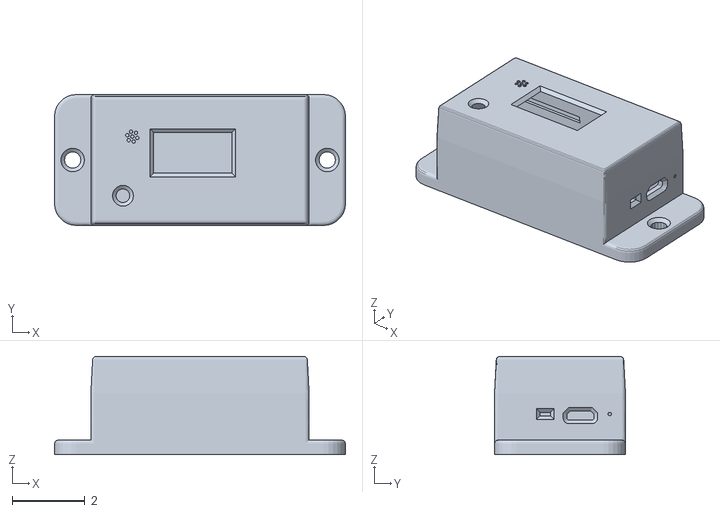
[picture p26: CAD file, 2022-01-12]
3D/Сборка/case.stl
8.00 x 3.60 x 2.70

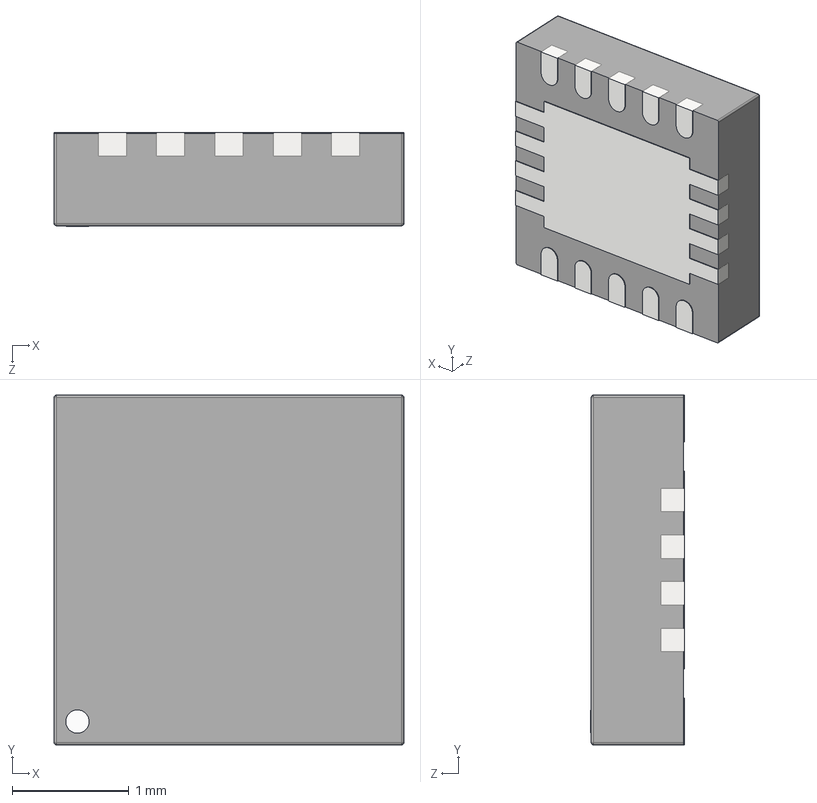
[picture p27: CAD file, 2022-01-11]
PCB/Curse_PCB/3d/User Library-SON10_3x3x0_8mm.STEP
3.00 x 3.00 x 0.805 mm

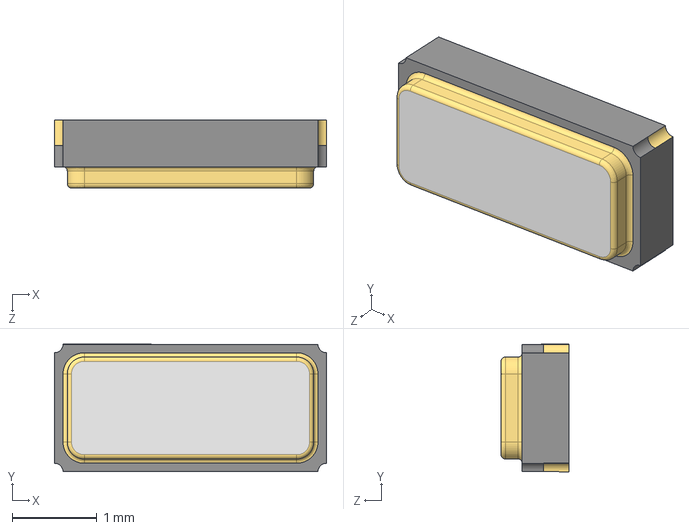
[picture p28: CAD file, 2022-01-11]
PCB/Curse_PCB/3d/User Library-NDK_NX3215SA.STEP
3.20 x 1.50 x 0.8 mm

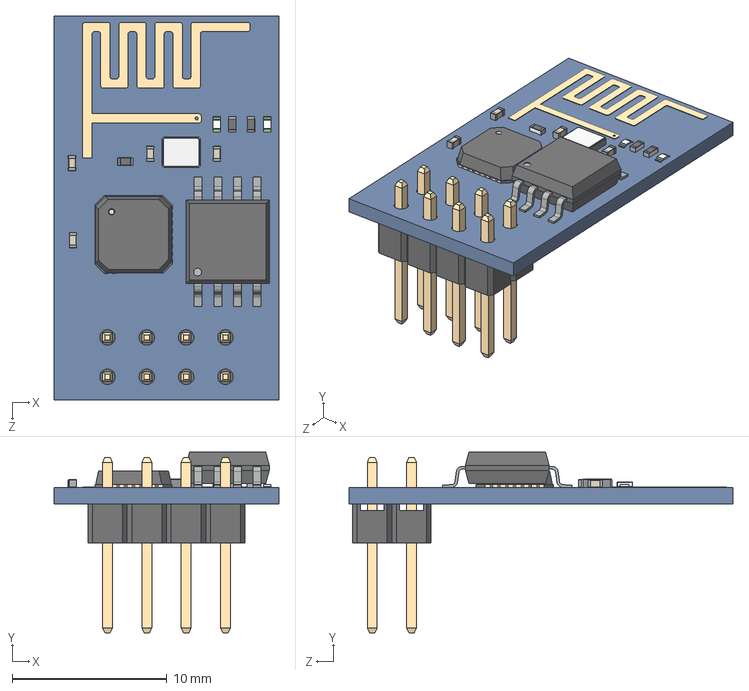
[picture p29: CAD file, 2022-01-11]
PCB/Curse_PCB/3d/User Library-ESP8266 ESP-01.step
14.5 x 11.7 x 24.8 mm

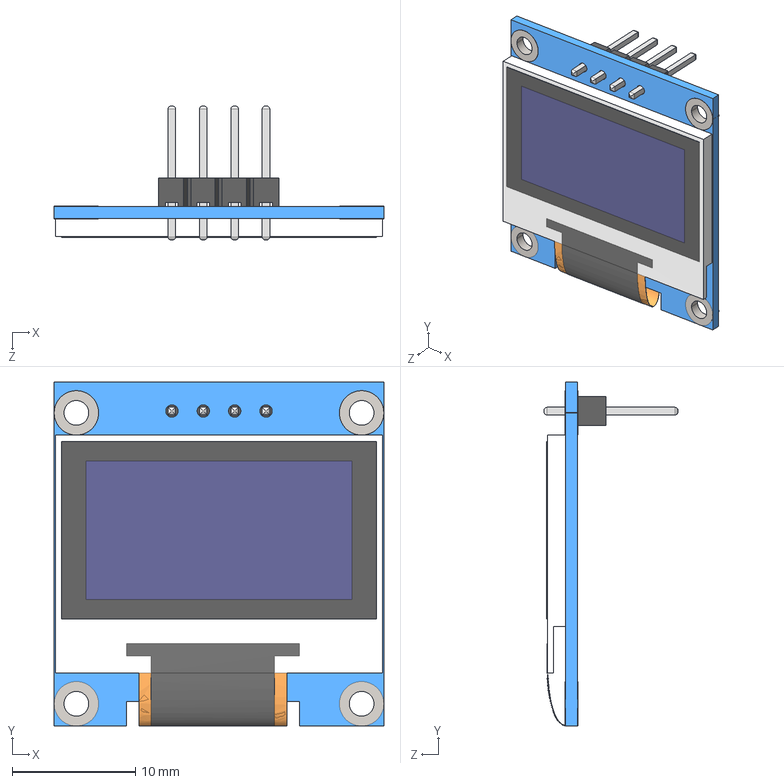
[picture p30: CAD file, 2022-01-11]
PCB/Curse_PCB/3d/User Library-128x64I2COLEDDisplayAdafruit.step
26.7 x 27.9 x 10.8 mm

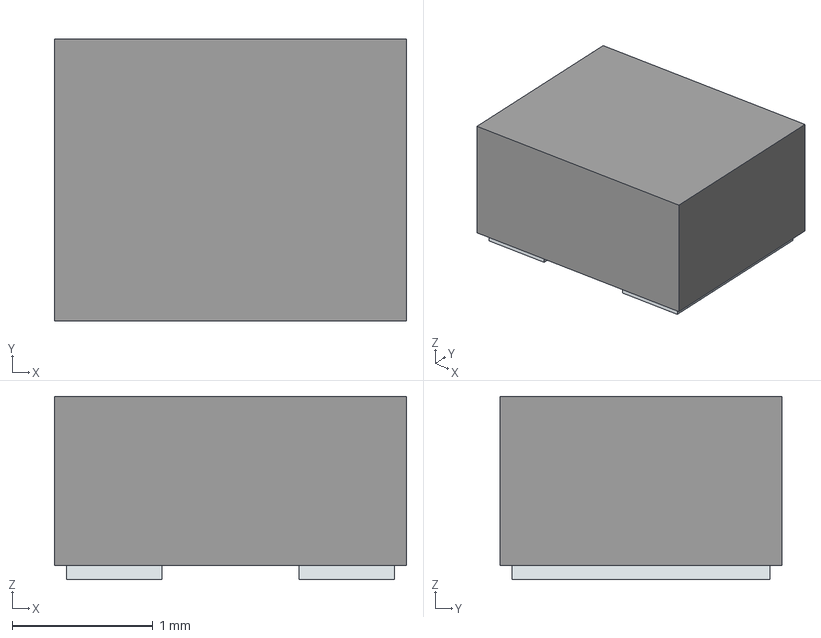
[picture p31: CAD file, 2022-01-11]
PCB/Curse_PCB/3d/VLS252012CX-1R0M-1.stp
2.50 x 2.00 x 1.30 mm
Pins

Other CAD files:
3D/Сборка/Чертеж устройства.dwg
DOCS/Плата Сборочный.dwg
3D/Сборка/Сборка_Датчик с поясн.dwg
3D/Сборка/OldVersions/Чертеж устройства.0010.dwg
DOCS/OldVersions/Плата Сборочный.0011.dwg
3D/Сборка/OldVersions/case.0023.dwg
3D/Сборка/OldVersions/Сборка_Датчик с поясн.0001.dwg
3D/case_down.ipt
3D/step_pcb/COMPOUND.ipt
3D/step_pcb/COMPOUND_4.ipt
3D/step_pcb/C_0603_1608Metric.iam
3D/step_pcb/C_0805_2012Metric.iam
3D/step_pcb/Curse_PCB PCB.ipt
3D/step_pcb/Curse_PCB.iam
3D/step_pcb/LED_0603_1608Metric.iam
3D/step_pcb/LFPAK56.iam
3D/step_pcb/OldVersions/C_0603_1608Metric.0001.iam
3D/step_pcb/OldVersions/C_0805_2012Metric.0001.iam
3D/step_pcb/OldVersions/Curse_PCB.0001.iam
3D/step_pcb/OldVersions/LED_0603_1608Metric.0001.iam
3D/step_pcb/OldVersions/LFPAK56.0001.iam
3D/step_pcb/OldVersions/PinSocket_1x04_P2.54mm_Vertical.0001.iam
3D/step_pcb/OldVersions/PinSocket_2x04_P2.54mm_Vertical_SMD.0001.iam
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

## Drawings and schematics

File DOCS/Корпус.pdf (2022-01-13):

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

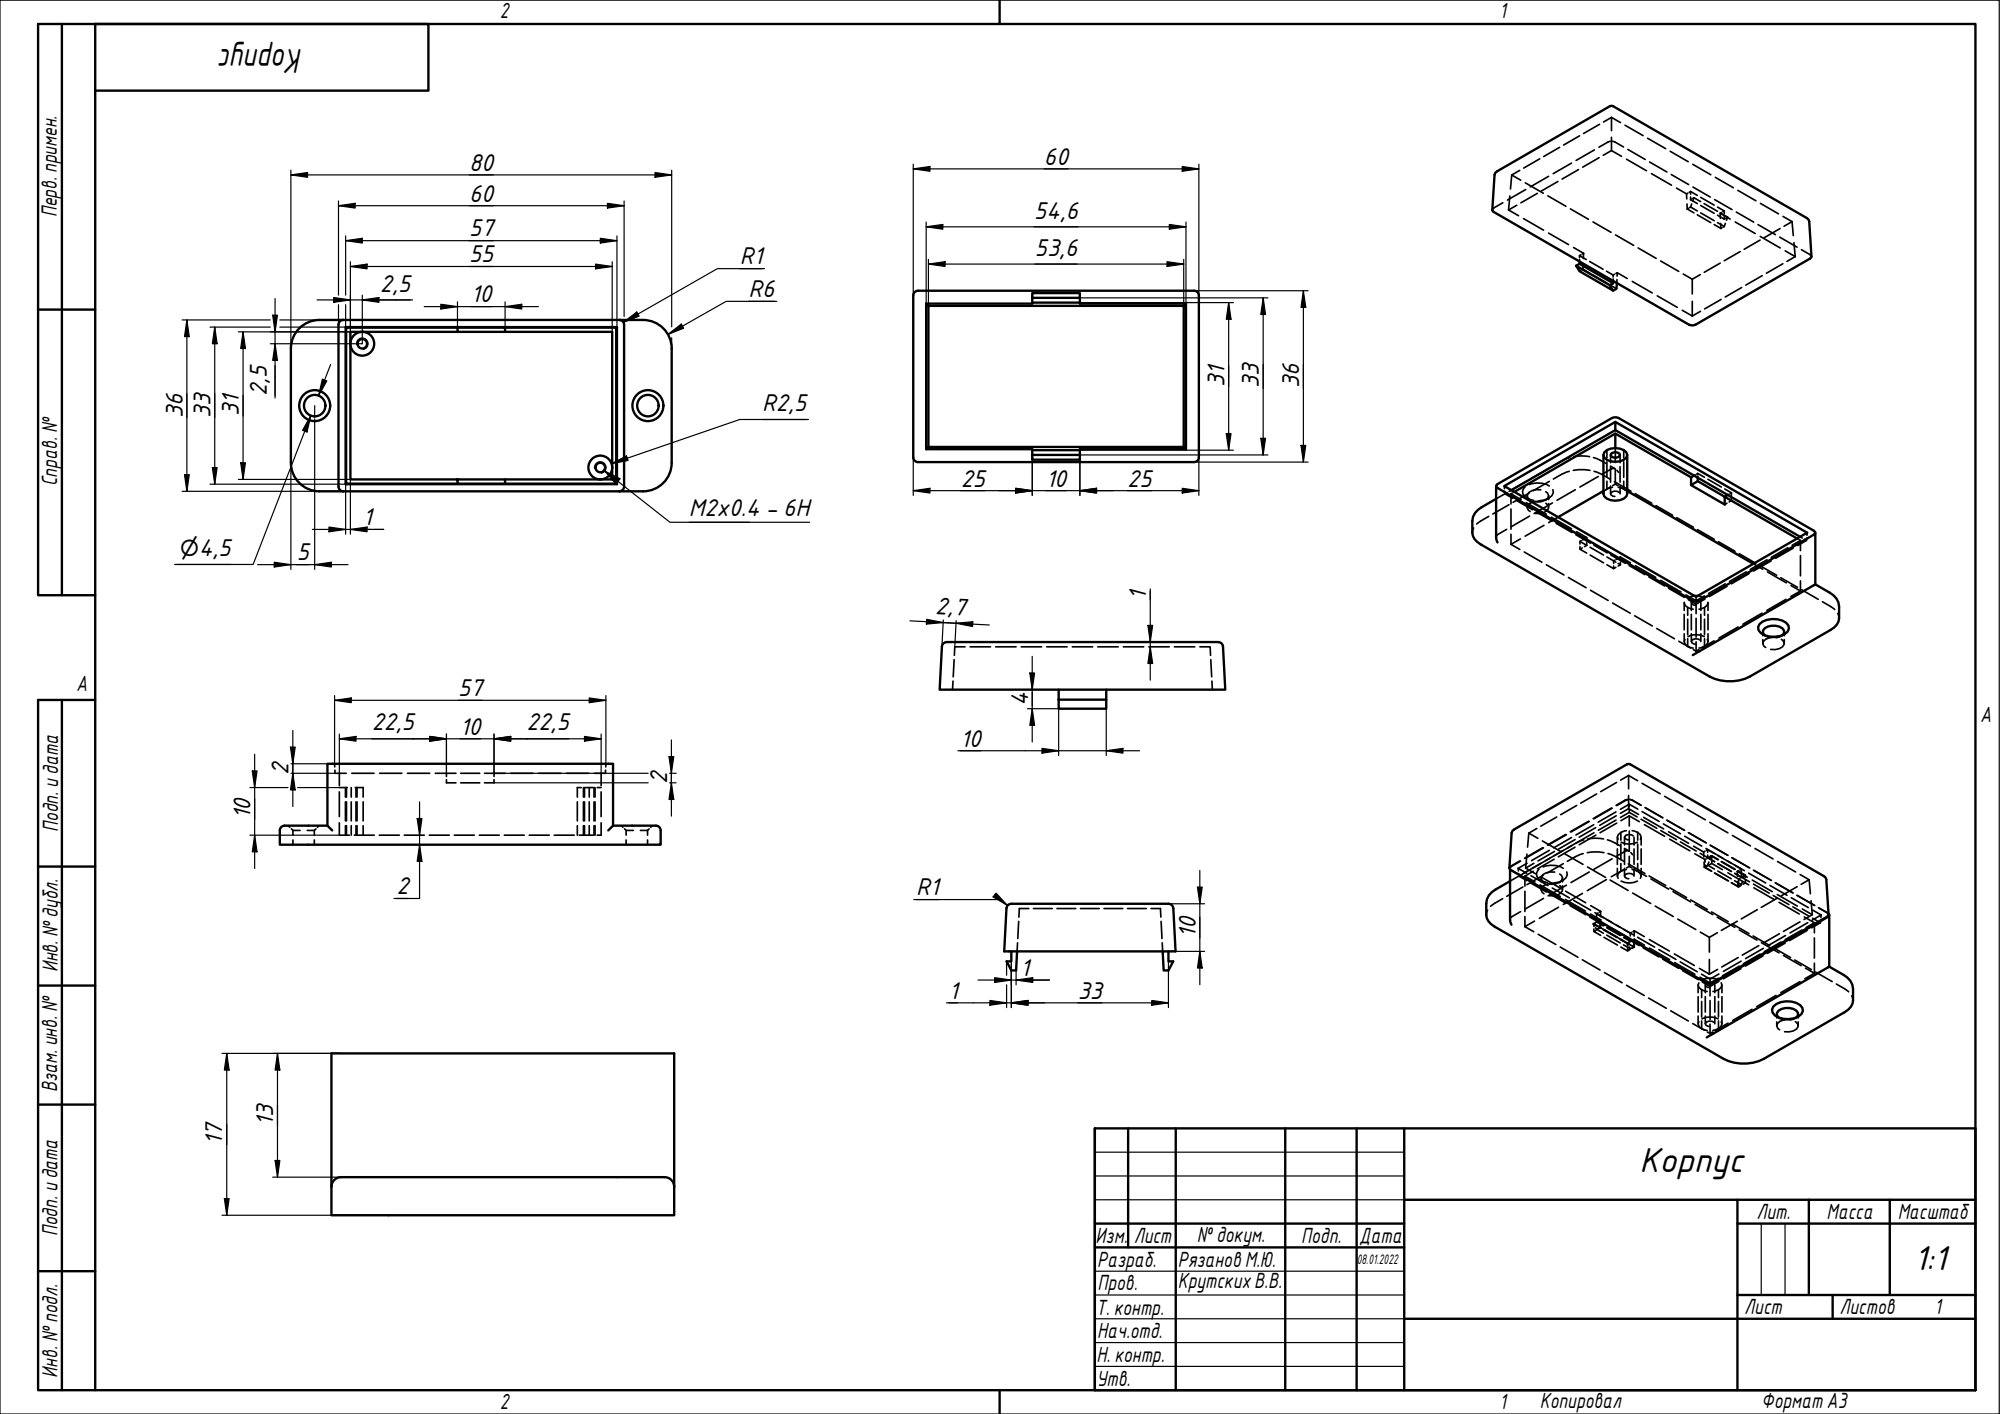
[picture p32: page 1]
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

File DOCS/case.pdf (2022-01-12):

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

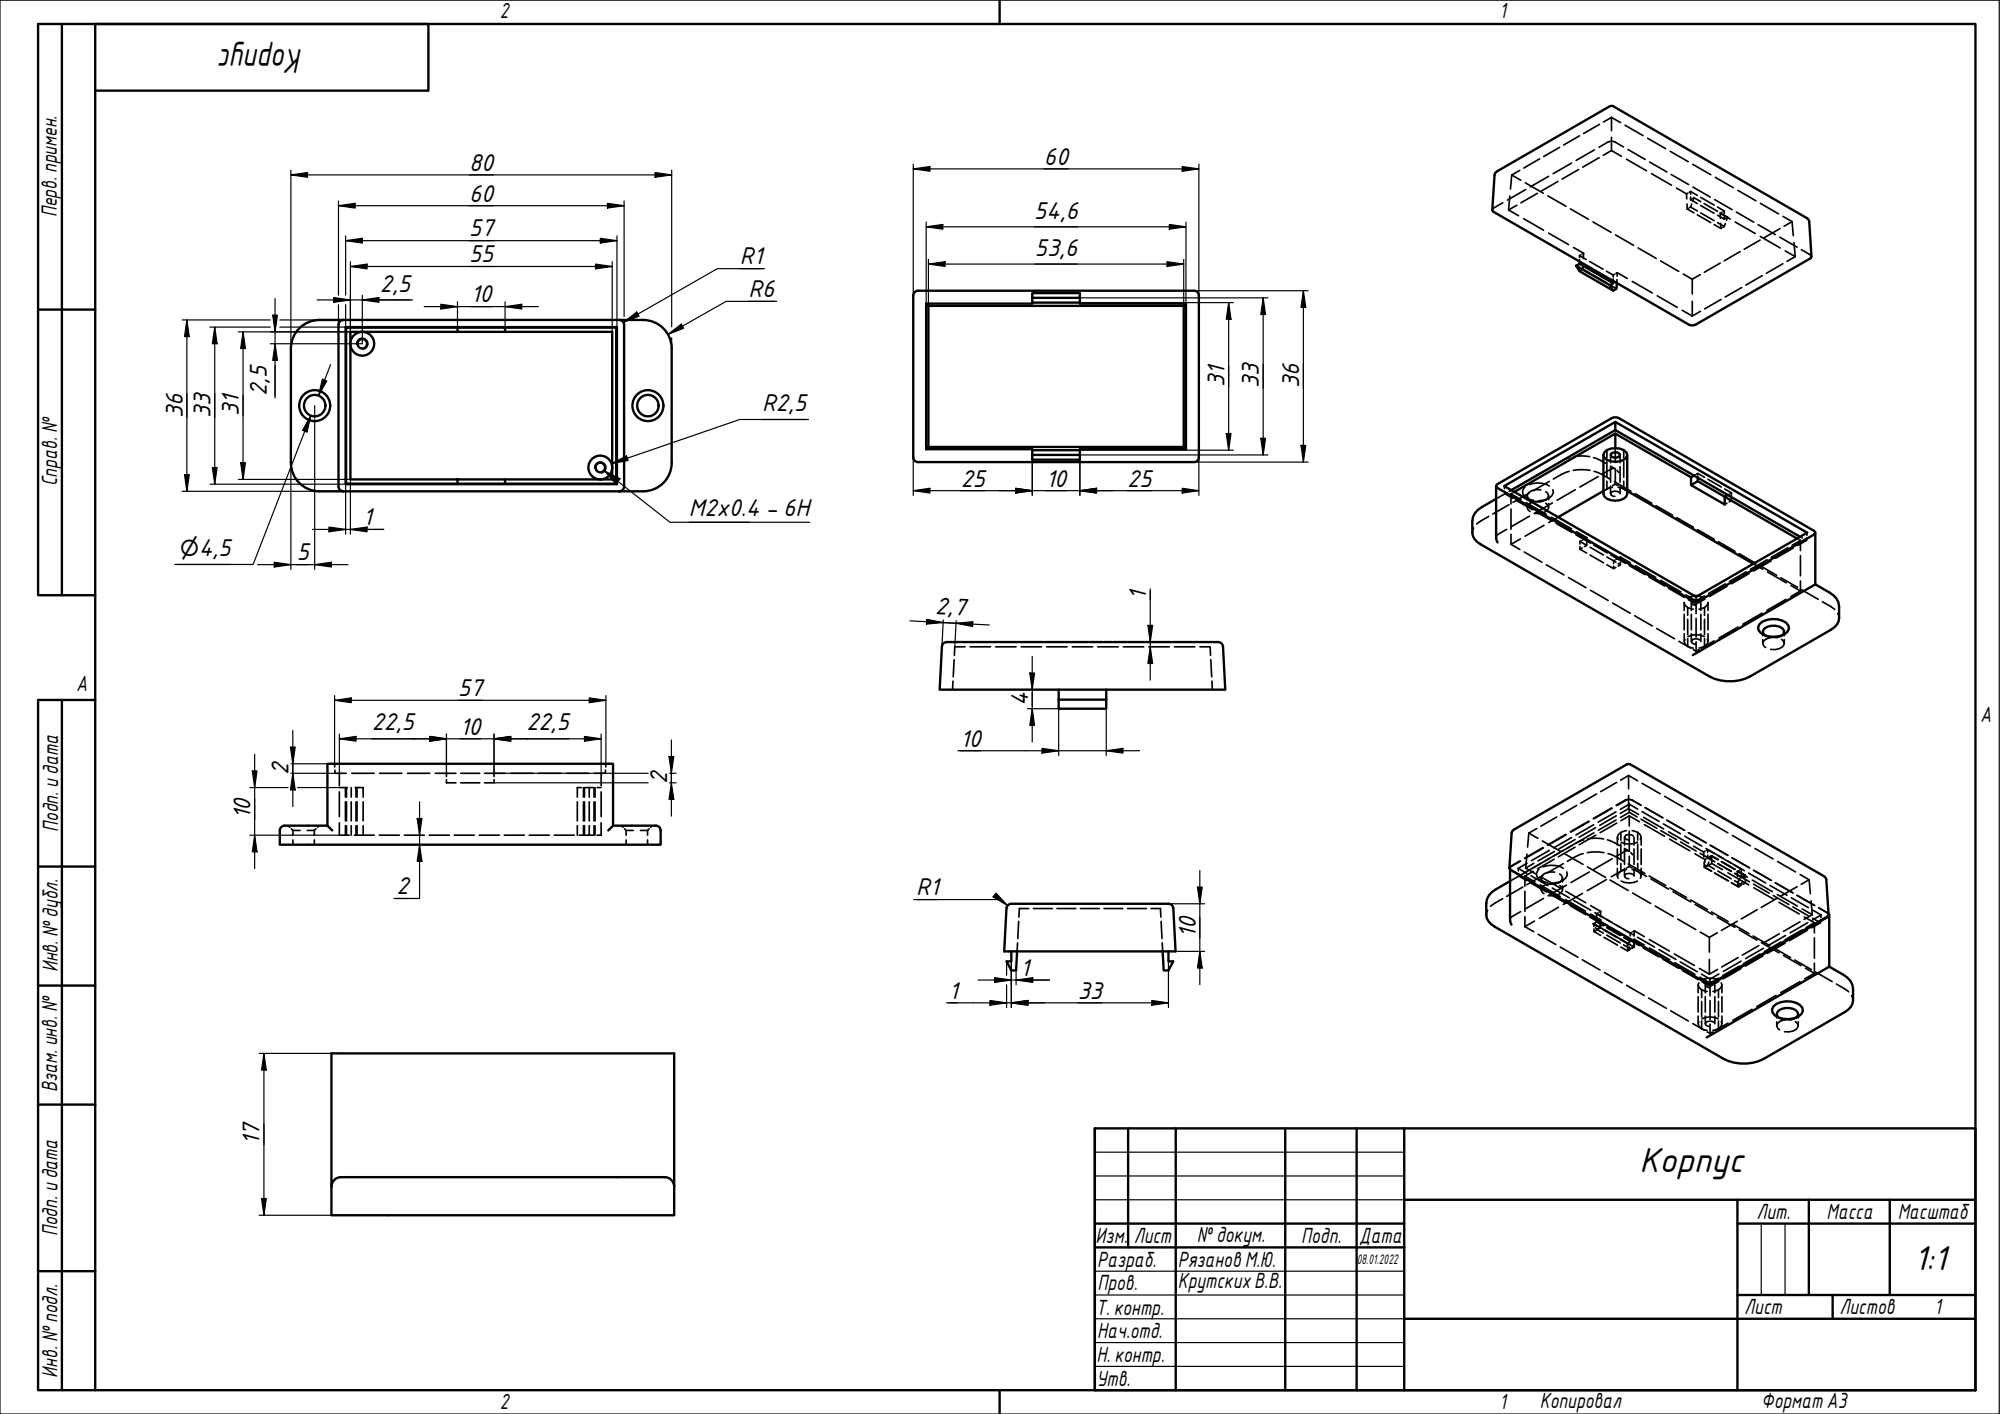
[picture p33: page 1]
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

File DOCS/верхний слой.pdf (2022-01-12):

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

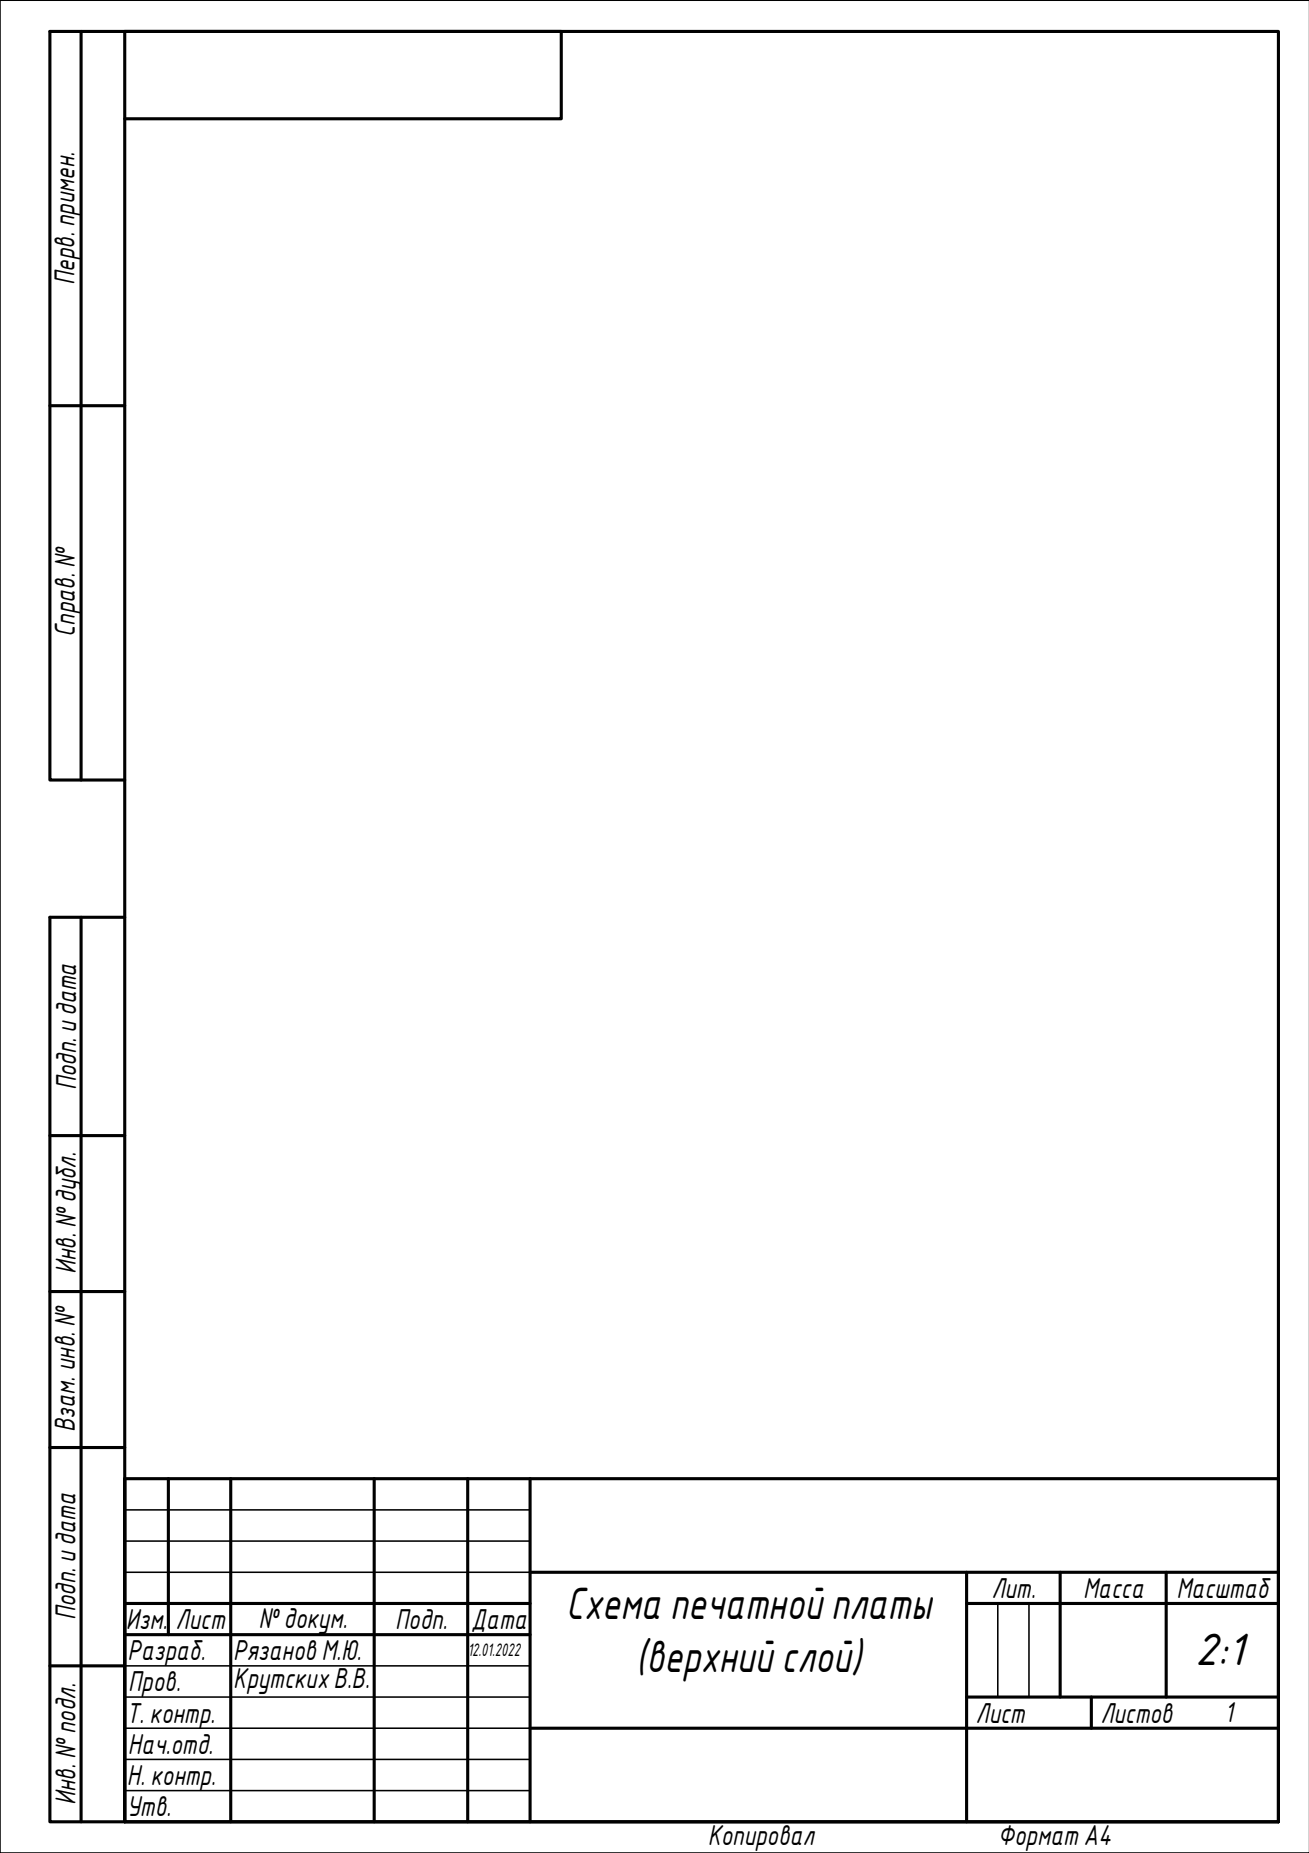
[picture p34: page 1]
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

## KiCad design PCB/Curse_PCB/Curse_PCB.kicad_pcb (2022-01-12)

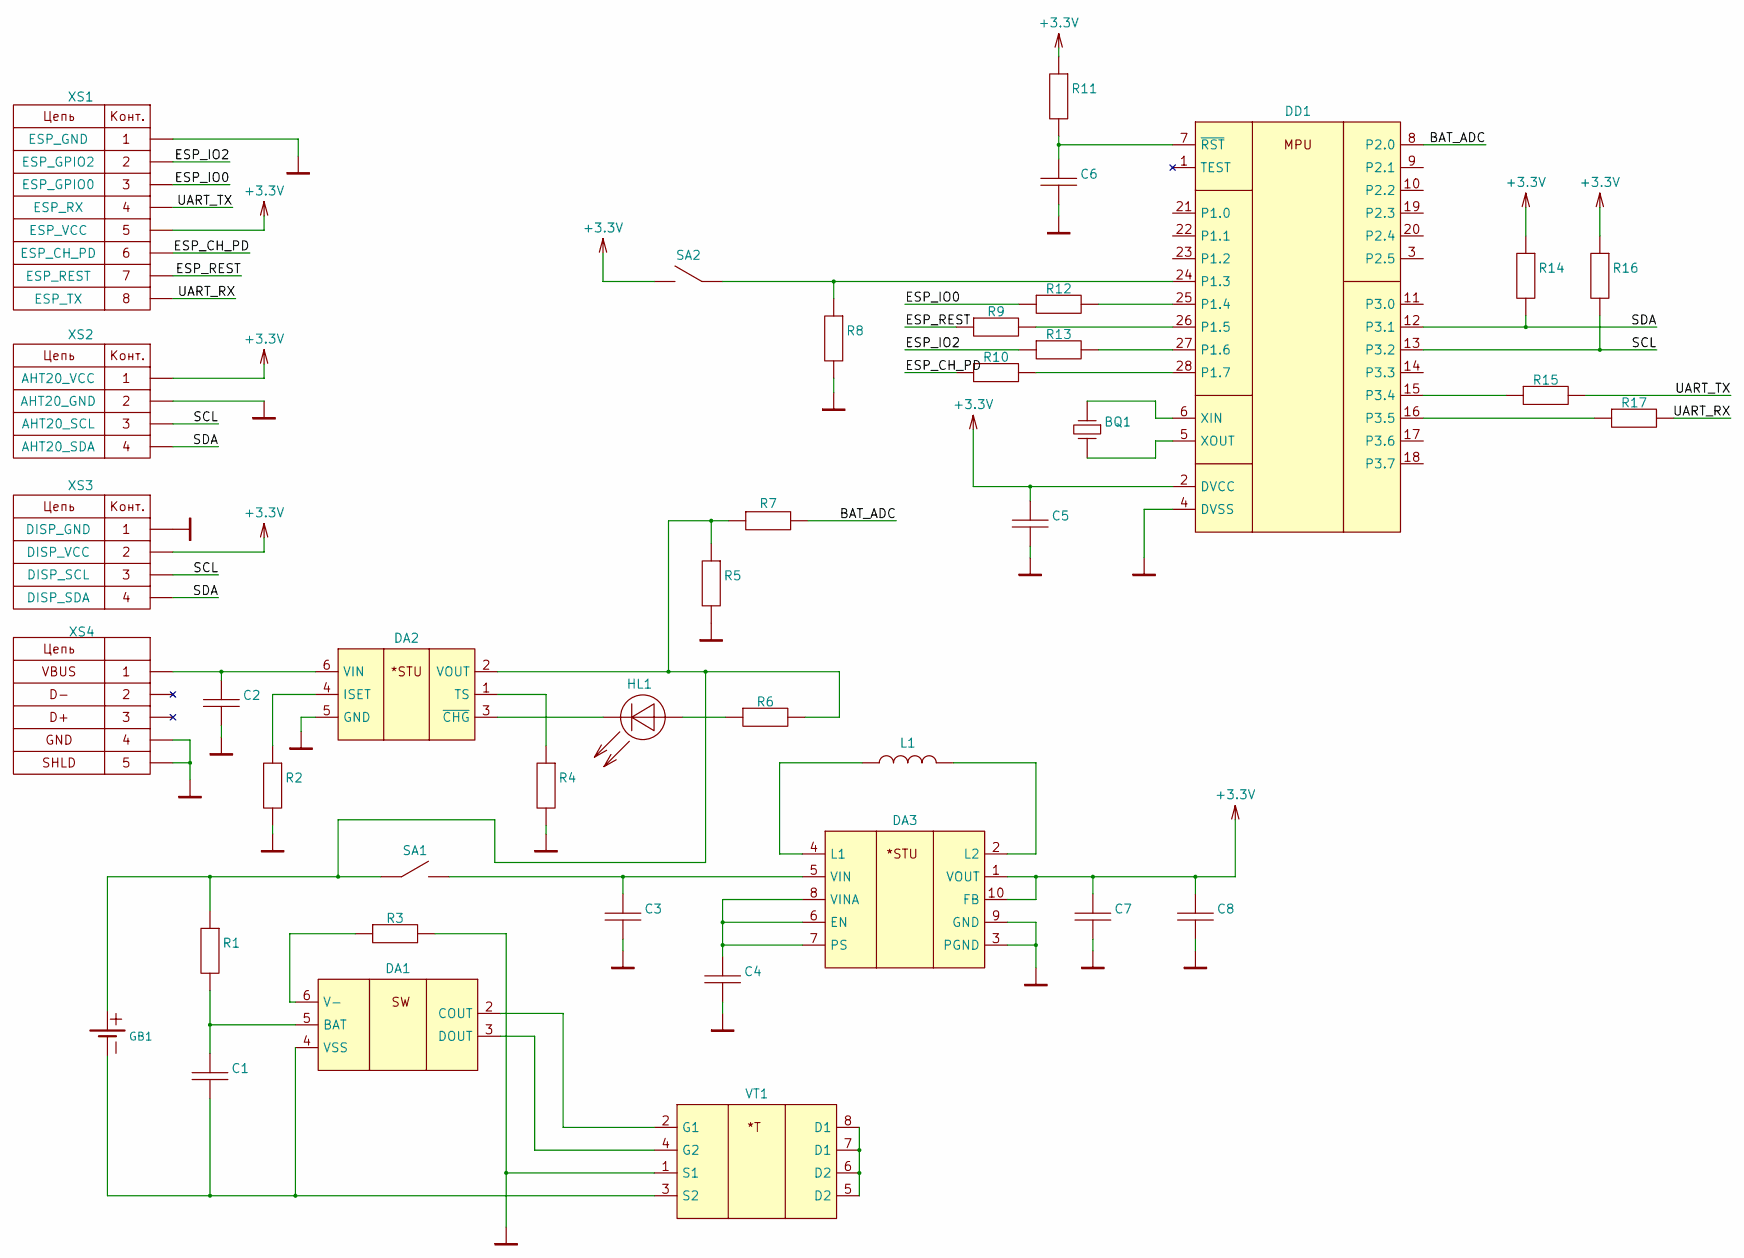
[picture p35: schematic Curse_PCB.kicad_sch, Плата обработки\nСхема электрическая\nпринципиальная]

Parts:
BQ1: 32.768 kHz 03215C2; Crystal_SMD_3215-2Pin_3.2x1.5mm
C1, C4, C5: 0.1 мкФ-NP0-50В ±5% 0603; C_0603_1608Metric
C2: 1 мкФ-NP0-16В ±5% 0805; C_0805_2012Metric
C3, C7, C8: 10 мкФ-NP0-16В ±5% 0805; C_0805_2012Metric
C6: 2200 пФ-NP0-50В ±5% 0603; C_0603_1608Metric
DA1: BQ29737 WSON-6; WSON-6_1.5x1.5mm_P0.5mm
DA2: BQ21040; SOT-23-6
DA3: TPS63031 WSON-10; WSON-10-1EP_2.5x2.5mm_P0.5mm_EP1.2x2mm_ThermalVias
DD1: MSP430F2112IPW TSSOP-28; TSSOP-28_4.4x9.7mm_P0.65mm
GB1: GB_BATTERY-KGL_Power
HL1: HL_LED; LED_0603_1608Metric
L1: VLS252010CX-1R5M-1 1,5 мкГн 2010; VLS252012CX
R1: 330 Ом ±5% 0603; R_0603_1608Metric
R2: 1,0 кОм ±1% 0603; R_0603_1608Metric
R3: 2,2 кОм ±5% 0603; R_0603_1608Metric
R4, R5, R7, R14, R16: 10 кОм ±5% 0603; R_0603_1608Metric
R6: 1,5 кОм ±5% 0603; R_0603_1608Metric
R8: 100 кОм ±5% 0603; R_0603_1608Metric
R9, R10, R12, R13, R15, R17: 510 Ом ±5% 0603; R_0603_1608Metric
R11: 47 кОм ±5% 0603; R_0603_1608Metric
SA1: PTS645VM58-2 LFS; SW_SPDT_PCM12
SA2: PTS645VM58-2 LFS; SW_Push_1P1T_NO_6x6mm_H9.5mm
VT1: BUK9K5R1-30E LFPAK56D; LFPAK56D
XS1: PBD-8; PinSocket_2x04_P2.54mm_Vertical_SMD
XS2, XS3: PBS-4; PinSocket_1x04_P2.54mm_Vertical
XS4: USB_A; USB_Micro-B_Molex_47346-0001

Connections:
+3.3V: C5.1, C7.1, C8.1, DA3.1 (VOUT), DA3.10 (FB), DD1.2 (DVCC), R11.1, R14.1, R16.1, SA2.2, XS1.5, XS2.1, XS3.2
/BAT_ADC: DD1.8 (P2.0), R7.2
/ESP_CH_PD: R10.1, XS1.6
/ESP_IO0: R12.1, XS1.3
/ESP_IO2: R13.1, XS1.2
/ESP_REST: R9.1, XS1.7
/SCL: DD1.13 (P3.2), R16.2, XS2.3, XS3.3
/SDA: DD1.12 (P3.1), R14.2, XS2.4, XS3.4
/UART_RX: R17.2, XS1.8
/UART_TX: R15.2, XS1.4
EXP: C2.2, C3.2, C4.2, C5.2, C6.2, C7.2, C8.2, DA2.5 (GND), DA3.3 (PGND), DA3.9 (GND), DA3.11 (EXP), DD1.4 (DVSS), R2.2, R3.2, R4.2, R5.2, R8.2, VT1.1 (S1), XS1.1, XS2.2, XS3.1, XS4.4, XS4.5
unnamed: BQ1.1, DD1.6 (XIN)
unnamed: BQ1.2, DD1.5 (XOUT)
unnamed: C1.1, DA1.5 (BAT), R1.2
unnamed: C1.2, DA1.4 (VSS), GB1.2, VT1.3 (S2)
unnamed: C2.1, DA2.6 (VIN), XS4.1
unnamed: C3.1, DA3.5 (VIN), SA1.2
unnamed: C4.1, DA3.6 (EN), DA3.7 (PS), DA3.8 (VINA)
unnamed: C6.1, DD1.7 (~RST), R11.2
unnamed: DA1.2 (COUT), VT1.2 (G1)
unnamed: DA1.3 (DOUT), VT1.4 (G2)
unnamed: DA1.6 (V-), R3.1
unnamed: DA2.1 (TS), R4.1
unnamed: DA2.2 (VOUT), GB1.1, R1.1, R5.1, R6.2, R7.1, SA1.1
unnamed: DA2.3 (~CHG), HL1.1 (K)
unnamed: DA2.4 (ISET), R2.1
unnamed: DA3.2 (L2), L1.2
unnamed: DA3.4 (L1), L1.1
unnamed: DD1.15 (P3.4), R15.1
unnamed: DD1.16 (P3.5), R17.1
unnamed: DD1.24 (P1.3), R8.1, SA2.1
unnamed: DD1.25 (P1.4), R12.2
unnamed: DD1.26 (P1.5), R9.2
unnamed: DD1.27 (P1.6), R13.2
unnamed: DD1.28 (P1.7), R10.2
unnamed: HL1.2 (A), R6.1
unnamed: VT1.5 (D2), VT1.6 (D2), VT1.7 (D1), VT1.8 (D1)

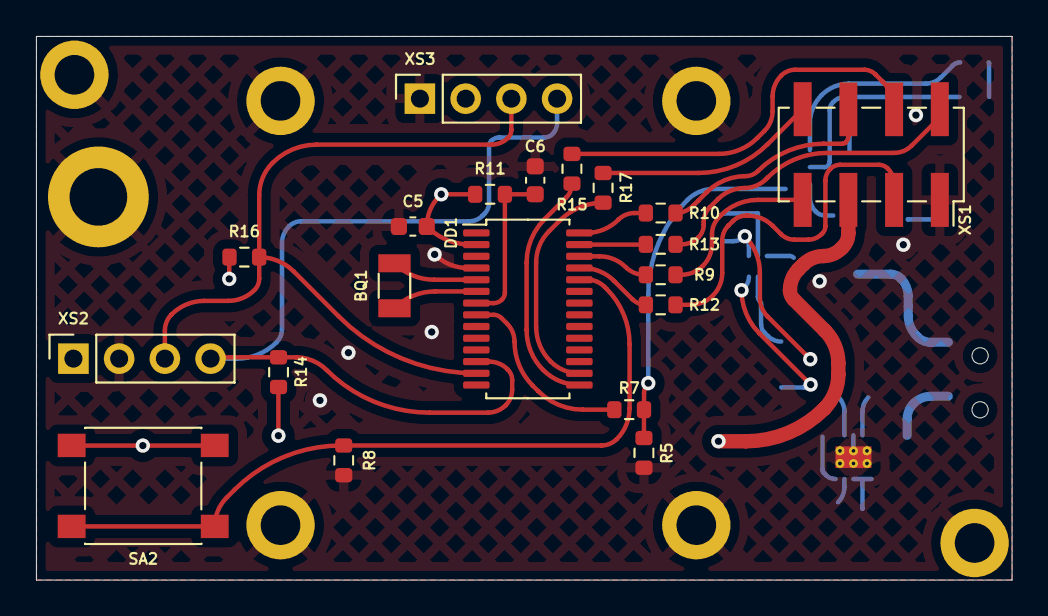
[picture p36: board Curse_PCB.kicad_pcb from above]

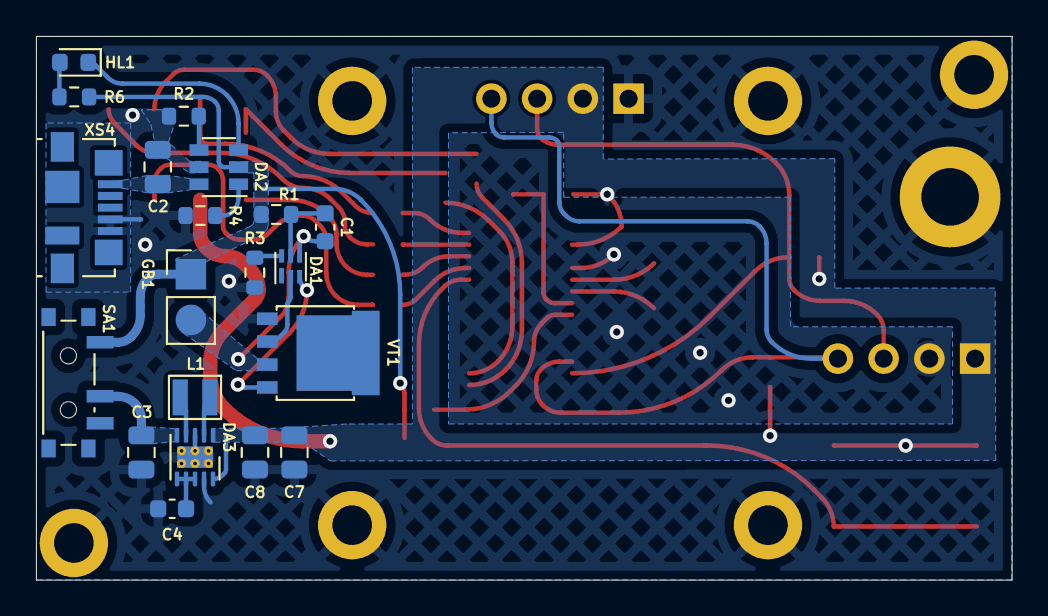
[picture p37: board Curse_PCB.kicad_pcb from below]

Board: 2 copper layers, 54.2 x 30.2 mm, 40 parts (20 on the bottom side), 36 nets.

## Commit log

2021-10-11 SCH + PCB
    [Curse_PCB.kicad_pcb, Curse_PCB.sch]
2021-10-18 Create Схема структурная.pdf
2021-10-18 Update Схема структурная.pdf
2021-10-19 схема
    [Curse_PCB.sch]
2022-01-08 Create пояснительная записка.docx
2022-01-10 pcb almost done
    [Curse_PCB.kicad_pcb, Curse_PCB.kicad_sch]
2022-01-10 сборка
    [Сборка_Датчик.iam]
2022-01-12 almost done
    [Curse_PCB-B_Cu.dxf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]
2022-01-12 нужна структурная схема!!!
2022-01-13 ВСЁ!
    [case.0022.dwg, case.0023.dwg, case.dwg]
2022-01-13 ФАСКИ
    [Чертеж устройства.0008.dwg, Чертеж устройства.0010.dwg, Чертеж устройства.dwg]
2022-01-14 исправления
2022-01-14 удалены файлы картинок
2022-01-14 чистка
    [Curse_PCB-B_Courtyard.dxf, Curse_PCB-B_Cu.dxf, Curse_PCB-B_Silkscreen.dxf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]
2022-01-14 финал
